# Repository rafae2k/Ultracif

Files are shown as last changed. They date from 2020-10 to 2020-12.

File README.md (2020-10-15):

<p align="center">
  Ultracif
</p></br>

### O UltraCif é um equipamento de descontaminação de máscaras através de luz ultravioleta para reutilização rápida e segura. Ele foi desenvolvido para amparar profissionais da saúde na luta contra a pandemia do COVID-19.

##### 1 - [Bibliografia](https://github.com/rafae2k/Ultracif/tree/main/Bibliografia)

  ###### Nesta seção você encontrará os principais artigos utilizados para pesquisa e desenvolvimento do Ultracif.

##### 1.1 - [Datasheet](https://github.com/rafae2k/Ultracif/tree/main/Datasheet)
  
  ###### Nesta seção você encontrará os datasheets dos principais componentes utilizados no Ultracif.

##### 2 - [Dosimetria](https://github.com/rafae2k/Ultracif/tree/main/Dosimetria)
  
  ###### Nesta seção é apresentado o programa elaborado em MATLAB para geração dos dados e graficos de irradiancia baseados nos dados da fabricante de lâmpadas UVC OSRAM.

##### 3 - [CAD](https://github.com/rafae2k/Ultracif/tree/main/CAD)

  ###### Nesta seção você encontrará os arquivos 3D dos componentes do Ultracif.

##### 4 [Eletroeletronica](https://github.com/rafae2k/Ultracif/tree/main/Eletroeletronica)
  
  ###### Nesta seção você encontrará os arquivos relativos ao desenvolvimento do PCB da placa controladora e diagrama do circuito elétrico.

 ##### 4.1 - [Firmware](https://github.com/rafae2k/Ultracif/tree/main/Eletroeletronica/Firmware)
   
   ###### Nesta seção você encontrará os arquivos do código-fonte utilizados no firmware do Ultracif.
  
##### 5 - [Lista de Materiais](https://github.com/rafae2k/Ultracif/tree/main/Lista%20de%20Materiais)
   
   ###### Nesta seção você encontrará a lista com todos os materiais utilizados para montagem do Ultracif.

##### 6 - [Orientações Gerais](https://github.com/rafae2k/Ultracif/tree/main/Orienta%C3%A7%C3%B5es)
   
   ###### Nesta seção você encontrará todas as orientações necessárias para operação do equipamento.

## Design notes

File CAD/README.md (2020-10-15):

# CAD

#### Nesta seção você encontrará os arquivos 3D dos componentes do Ultracif.

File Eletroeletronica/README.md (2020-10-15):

# ELETROELETRONICA
  ###### Nesta seção você encontrará os arquivos relativos ao desenvolvimento da placa controladora e diagrama do circuito elétrico.

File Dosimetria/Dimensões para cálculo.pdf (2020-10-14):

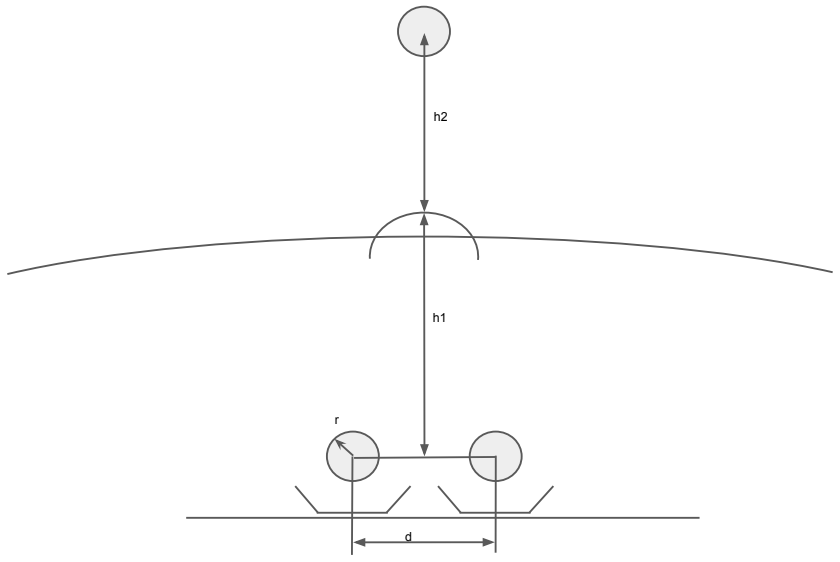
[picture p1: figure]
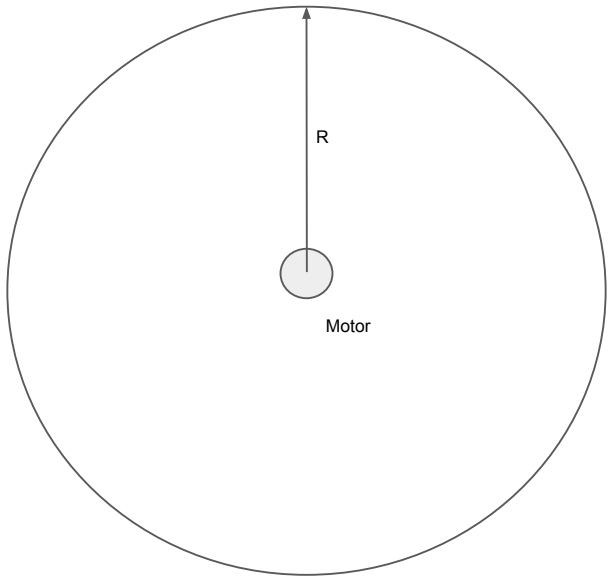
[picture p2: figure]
Motor R

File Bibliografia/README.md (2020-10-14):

# BIBLIOGRAFIA
  ###### Nesta seção você encontrará os principais artigos utilizados para pesquisa e desenvolvimento do Ultracif.

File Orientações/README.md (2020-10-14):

# ORIENTAÇÕES GERAIS
   ###### Nesta seção você encontrará todas as orientações necessárias para operação do equipamento.

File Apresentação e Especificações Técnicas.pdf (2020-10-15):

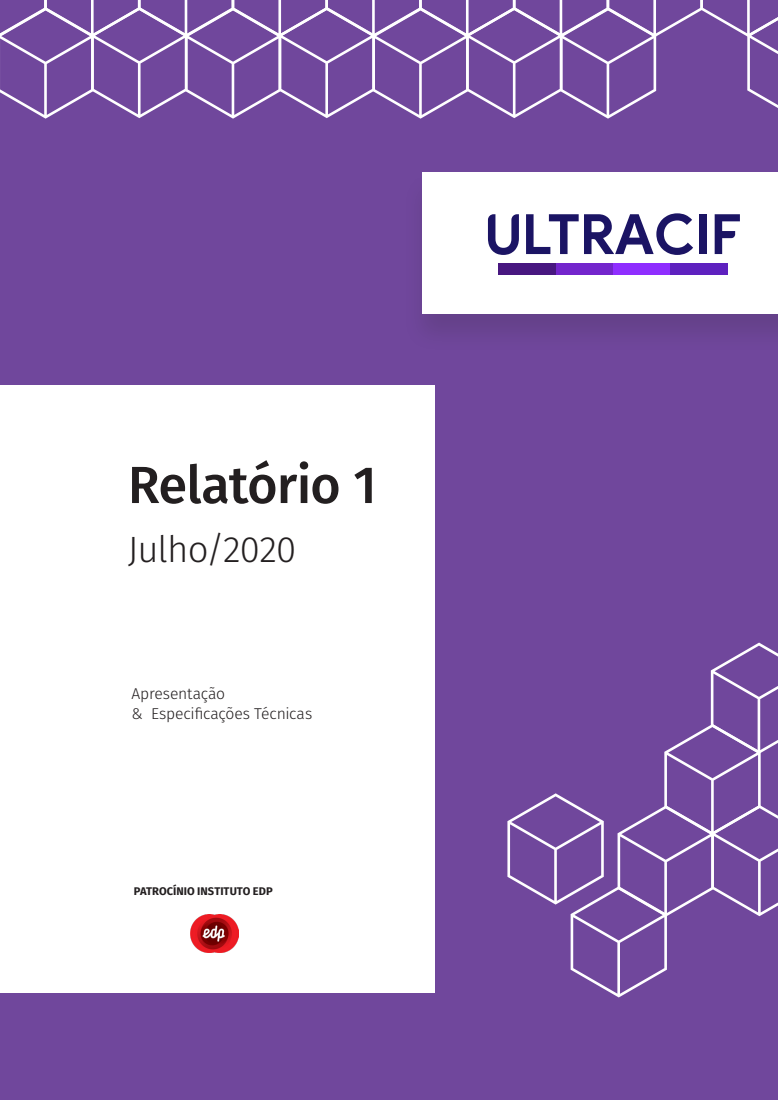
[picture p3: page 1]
Relatório 1; Julho/2020; Apresentação & Especificações Técnicas

PATROCÍNIO INSTITUTO EDP

No cenário de adversidades e imprevisibilidades em que o mundo se encontra, tem se tornado uma constante a busca por soluções inovadoras para os problemas correntes. É isso que norteia a Equipe ULTRACIF, formada por pessoas que acreditam no papel central da ciência e da tecnologia na geração de benefícios concretos para a sociedade.

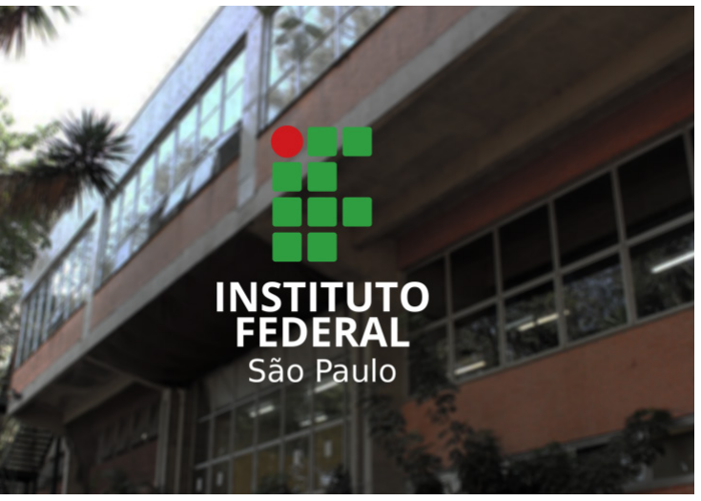
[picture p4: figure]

## Tergos / Bright Photomedicine

O Instituto Federal de Educação, Ciência e Tecnologia São Paulo (IFSP) é uma instituição pública federal especializada na oferta de educação científica, tecnológica e profissionalizante nas diferentes modalidades de ensino - técnico, superior e de pós-graduação. Fundada em 1909, como Escola de Aprendizes Artífices, é reconhecida tanto por sua excelência no ensino público gratuito de qualidade quanto pelo seu envolvimento em projetos capazes de promover benefícios e melhorias para a sociedade.

## Instituto Federal de São Paulo

A Bright Photomedicine é uma healthtech que combina big data, machine learning e inteligência artificial com a física e a medicina para criar o primeiro remédio digital do mundo. É afiliada da Tergos, empresa dedicada à pesquisa e ensino na mesma linha. Sua missão é propiciar aos pacientes alívio e cura da dor, de maneira eficaz, acessível, previsível e sem efeitos colaterais através da energia luminosa.

A equipe foi formada a partir de uma parceria entre o Instituto Federal de São Paulo (IFSP) e a Bright Photomedicine. Dessa união, surge o ULTRACIF, um equipamento inovador de desinfecção UV open-source, desenvolvido para amparar profissionais de saúde que têm lidado com a falta de equipamentos de proteção individual (EPI’s) na luta contra a pandemia do COVID-19.

# Sobre Institucional

2 | ULTRACIF

# ALEXANDRE CAMPO

Professor Titular do Instituto Federal de São Paulo – campus São Paulo Doutor em Engenharia Elétrica POLI-USP

# LUÍSA YAMAUCHI

Graduanda em Engenharia Naval -POLI-USP e Vice-Presidente do Centro Acadêmico de Engenharia Naval (CEN).

# RAFAEL FEITOZA

Graduando em Eng. de Controle e Automação
IFSP – campus São Paulo

# CADU PALMIERI

Engenheiro Eletrônico - IFSP Mestrando em
Engenharia Elétrica USP - EESC

# MARCELO SOUSA

Físico com doutorado em Low Level Light Therapy - Harvard Medical School CSO da empresa Bright Photomedicine

# Nosso Time

ULTRACIF | 3

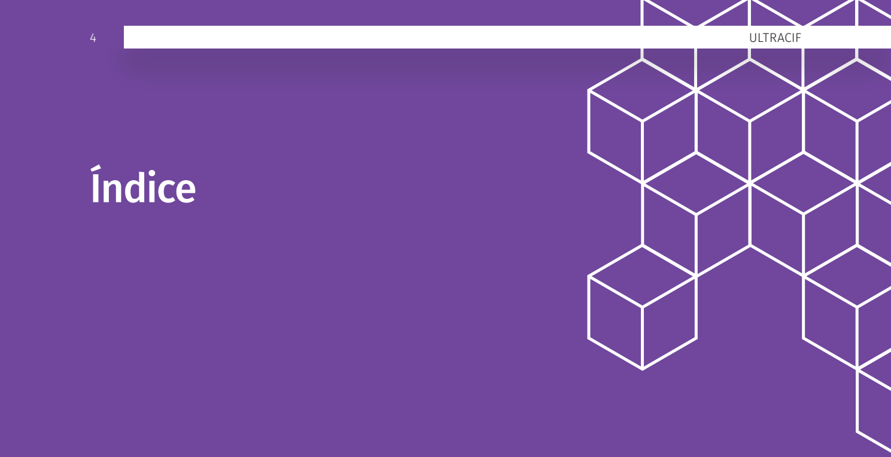
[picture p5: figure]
Índice

I. O Projeto | 05
II. Contexto / Justificativa | 07
III. Projeto Dosimétrico | 09
IV. Desenvolvimento / Modelos | 10
V. Componentes | 12
VI. Construção e Montagem | 14

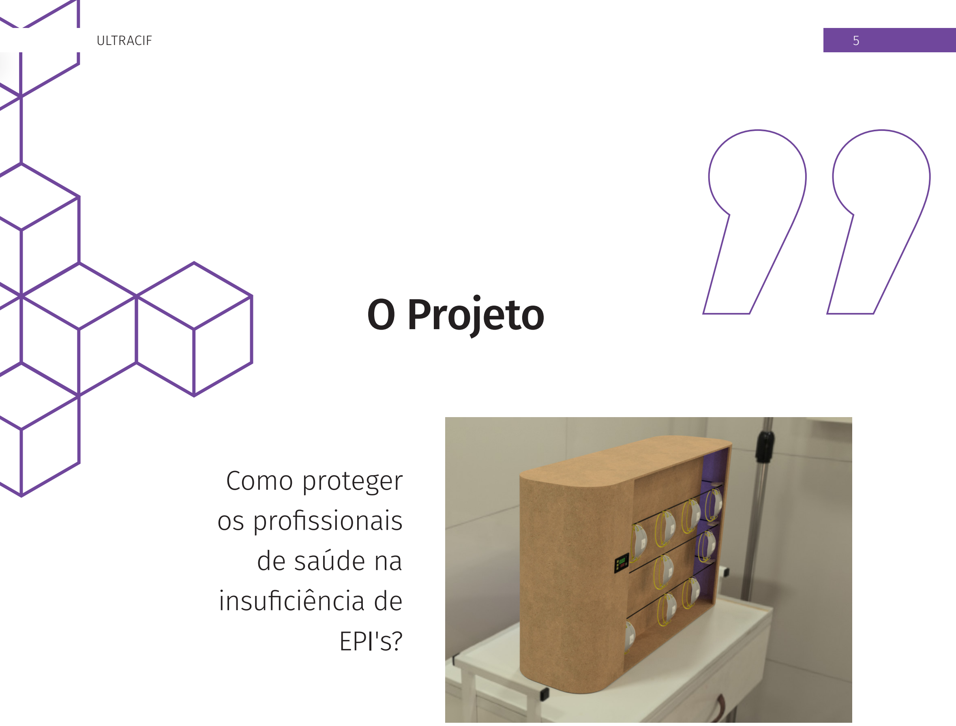
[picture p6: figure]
O Projeto; Como proteger os profissionais de saúde na insuficiência de EPI's?

A pandemia da COVID-19 tem
causado | grande | impacto | na
sociedade durante o ano de 2020, sobrecarregando o sistema de saúde e seus profissionais por todo o mundo.

Devido à carência de máscaras do tipo N95/PFF2-S, essenciais na proteção contra o vírus, surge a necessidade de se pensar em formas de atender a essa demanda, sendo uma delas o uso de dispositivos de descontaminação de equipamentos de proteção individual, possibilitando o reuso mais adequado destes.

Dentro | deste | contexto, | tem-
se como proposta de solução o desenvolvimento de um sistema de descontaminação de máscaras através de irradiação ultravioleta
germicida | (IUVG): | o ULTRACIF.

O projeto envolve duas principais inovações que definem a originalidade do equipamento. A primeira está relacionada à garantia de segurança no uso, uma vez que a radiação ultravioleta do tipo C é nociva aos tecidos humanos. Esta proteção consiste em uma câmara de descontaminação confinada para

ULTRACIF: DESCONTAMINAÇÃO RÁPIDA E SEGURA DE MÁSCARAS.

as máscaras, de modo que o usuário nunca fique exposto à UVC. A segunda trata do sistema de alimentação contínua das máscaras, permitindo que novas máscaras a serem descontaminadas sejam inseridas no processo sem a necessidade
de | interrupção | do | sistema.
A velocidade de movimentação do sistema de transporte de máscaras garante a exposição à dosagem correta de irradiação ultravioleta germicida, além de expor a máscara a diferentes ângulos de incidência da radiação.

# Um trabalho seguro é

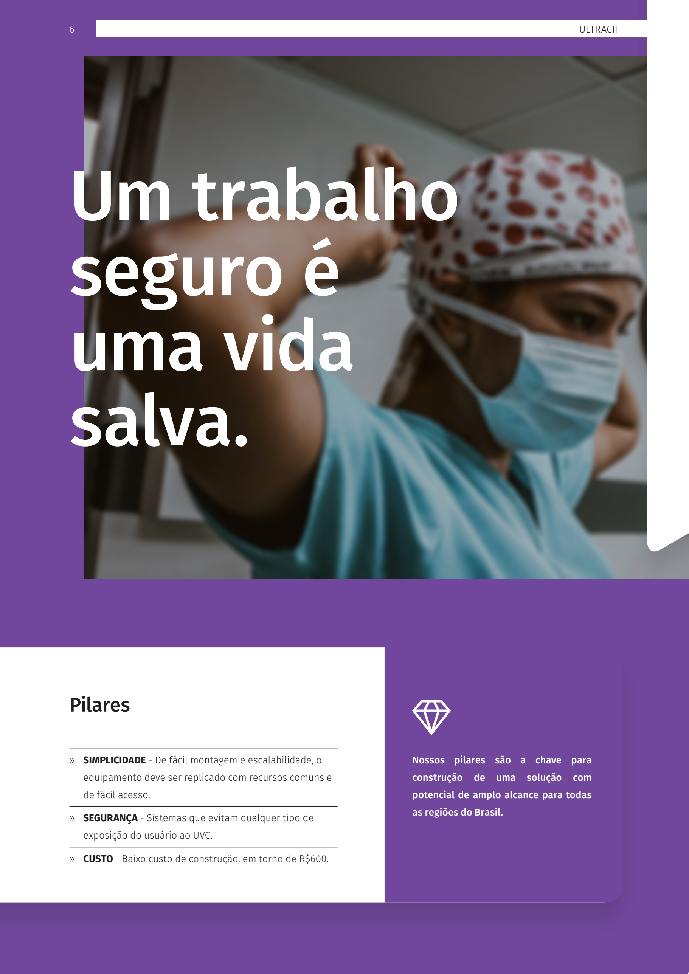
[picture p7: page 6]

# uma vida

salva.

# Pilares

» SIMPLICIDADE - De fácil montagem e escalabilidade, o equipamento deve ser replicado com recursos comuns e de fácil acesso.
» SEGURANÇA - Sistemas que evitam qualquer tipo de exposição do usuário ao UVC.
» CUSTO - Baixo custo de construção, em torno de R$600.

Nossos pilares são a chave para construção de uma solução com potencial de amplo alcance para todas as regiões do Brasil.

O fornecimento adequado de máscaras para os trabalhadores da saúde durante a pandemia global é um problema urgente de saúde pública.

O uso de máscaras N95 é recomendado como um dos principais meios de proteção dos profissionais de saúde (Mills et al., 2018)¹. Considerando que a pandemia do vírus SARS-CoV-2 tem seu principal canal de transmissão através das vias respiratórias, a disponibilidade deste EPI passa a ser um fator crítico. A alta demanda por este tipo de equipamento tem provocado sua falta em diversas localidades, tendo sido destacadas orientações para seu reuso de acordo com a ²NOTA TÉCNICA GVIMS/GGTES/ANVISA Nº 04/2020:

“O tempo de uso da máscara N95/PFF2 ou equivalente, em relação ao período de filtração contínua do dispositivo, deve considerar as orientações do fabricante. O número de reutilizações da máscara, pelo mesmo profissional, deve considerar as rotinas orientadas pelas CCIHs do serviço de saúde e constar no Protocolo.”

Segundo o boletim técnico de um fabricante de máscaras N95 (Decontamination Methods for 3M Filtering, Revisão 7)³, o processo de descontaminação deve atender aos seguintes requisitos: inativar o organismo alvo, tal como o vírus que causa COVID-19; não danificar a propriedade filtrante do dispositivo; não afetar a forma do dispositivo, impedindo seu correto uso; e ser um procedimento que garanta a segurança do usuário do respirador.

Um dos métodos apontados como efetivos para este processo é através do uso de irradiação ultravioleta germicida (IUVG). Segundo (Dai et al., 2012)⁴, a irradiação ultravioleta germicida é uma irradiação eletromagnética com um comprimento de onda compreendido na faixa entre 100 nm e 400 nm, sendo mais curto que a luz visível e mais longo que o raio-X.

# Contexto / Justificativa

¹MILLS, D. et al. Ultraviolet germicidal irradiation of influenza-contaminated N95 filtering facepiece respirators. American journal of infection control, v. 46, n. 7, p. e49– e55, jul. 2018.
²Nota técnica GVIMS/GGTES/ANVISA nº 04/2020 orientações para serviços de saúde: medidas de prevenção e controle que devem ser adotadas durante a assistência aos casos suspeitos ou confirmados de infecção pelo novo coronavírus (SARS-CoV2).
³Decontamination Methods for 3M Filtering Facepiece Respirators such as N95 Respirators. Technical Bulletin, Junho de 2020. Revisão 7
⁴DAI, T. et al. Ultraviolet C irradiation: an alternative antimicrobial approach to localized infections? Expert review of antiinfective therapy, v. 10, n. 2, p. 185–195, fev. 2012.

# Uma alternativa ao reuso de máscaras consiste na utilização de métodos de descontaminação

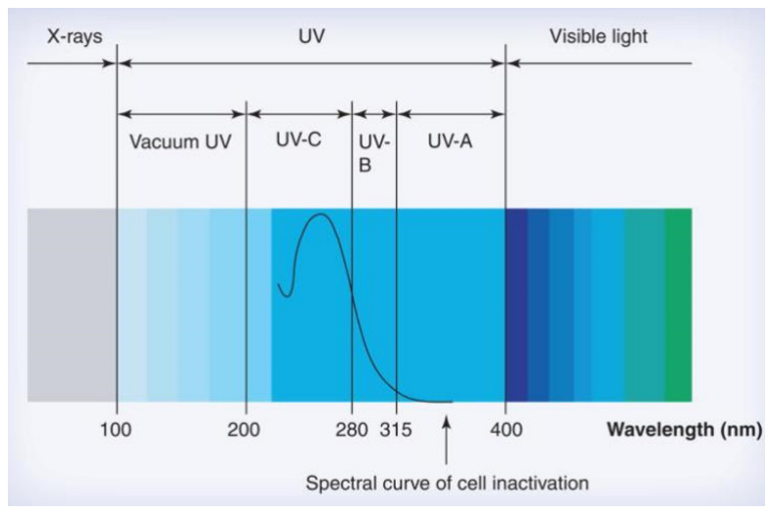
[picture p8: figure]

Figura 1: Espectro de radiação e curva de absorção e inativação de celulas virais.

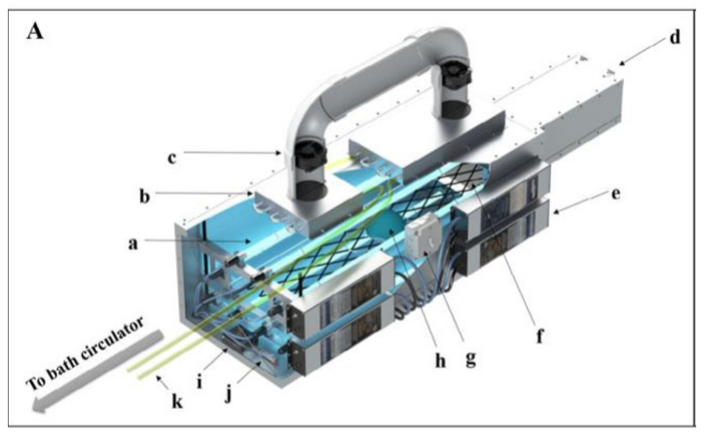
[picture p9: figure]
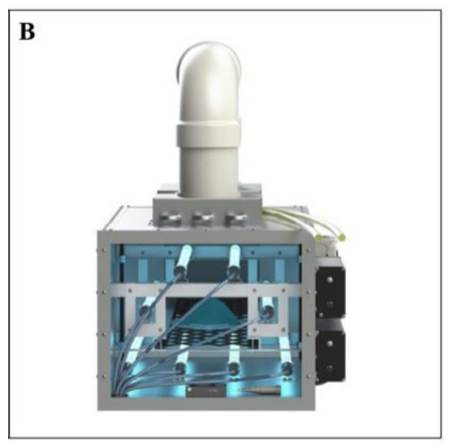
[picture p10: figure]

O trabalho apresenta a metodologia para a determinação da dosagem de radiação necessária para o processo de descontaminação, sendo apresentados os cálculos de acordo com a irradiância de uma lâmpada IUVG comercial:

O espectro do ultravioleta é dividido em quatro faixas, sendo que a faixa UVC é aquela compreendida entre 200 nm e 280 nm. Esta faixa de radiação tem a característica de ser absorvida com facilidade por ácidos nucleicos de organismos vivos, sendo uma faixa letal para estes.

O pico da ação germicida ocorre em 254 nm, sendo conhecida como espectro germicida, devendo ser utilizada com cuidados para evitar sua ação sobre tecidos humanos.

A geração do IUVG pode ser feita através de lâmpadas de vapor de mercúrio de baixa pressão de baixo custo. Recentemente também foram desenvolvidos light emitting diodes (Leds) que emitem radiação germicida, possibilitando um uso mais amplo deste tipo de ação.

Mills et al. (2018)¹ apresenta um estudo em que máscaras N95 de diversos fabricantes foram contami-nadas com vírus do tipo influenza (H1N1), tendo sido posteriormente submetidas a uma densidade de potência de 1 J/cm² por aproximadamente um minuto, sendo observada uma significativa redução, maior do que 3 log. No referido experimento foi construída uma câmara em que as máscaras foram inseridas para a execução do procedimento de descontaminação, conforme apresentado ao lado.

Figura 2: Dispositivo para a descontaminação de máscaras do tipo N95 por irradiação ultravioleta germicida (IUVG).

A dosagem de irradiação ultravioleta germicida (IUVG) deve ser calculada corretamente para que possam ser eliminados os patógenos presentes no material a ser descontaminado. Os cálculos da dosagem de IUVG dependem da fonte de radiação utilizada. No caso do modelo de lâmpada adotado para o projeto (OSRAM UV-C Puritec-HNS), tem-se que há emissão de radiação principalmente no comprimento de onda classificado como UV-C, de 254 nm.
De acordo com o fabricante, cada lâmpada possui um gráfico específico que descreve a irradiância em função da distância da lâmpada, sendo que o decaimento exponencial desta grandeza implica no uso de dois gráficos diferentes para representar a queda da dimensão. Num primeiro gráfico, o fabricante descreve a irradiância em W/m² em um raio de 0 a 0,5m de distância da superfície da lâmpada. Num segundo gráfico a irradiância é apresentada na faixa entre 0,5 m e 3 m de distância.
Para calcular a dosagem de IUVG na máscara, foi necessário determinar a função que melhor representa a irradiância em função da distância. Este cálculo foi desenvolvido para uma lâmpada OSRAM G13 através do programa MATLAB e é apresentado a seguir:

# Projeto Dosimétrico

Considerando que a lâmpada tem 1,3 cm de raio e aproximadamente 43,8 cm de comprimento, com potência total de 4W na faixa UV-C, nota-se que a irradiância em sua superfície é de 110 W/m².

A irradiância da lâmpada tubular se espalha ao redor da mesma de acordo com a função acima representada. Dessa forma, pode-se calcular a irradiância numa superfície perpendicular à lâmpada G13, de acordo com a figura a seguir:

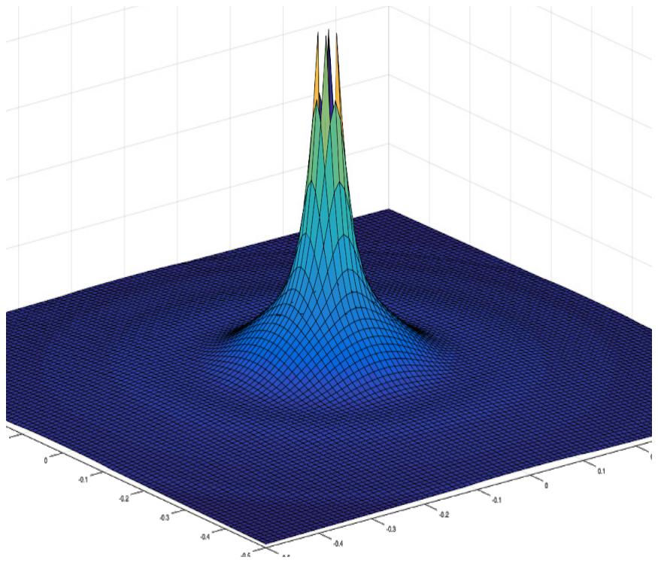
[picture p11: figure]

Figura 4 - Irradiância da Lâmpada UVC 15W OSRAM HNS

Deste modo é possível, definir a velocidade que o sistema de transporte das máscaras deverá ter para que estas recebam a dosagem de IUVG desejada.

No momento atual, o valor da dosagem calculada para um objeto movendo-se a 5 cm/s diante da lâmpada G13 chega a 70 Ws/m². O projeto deverá se desenvolver para definir a velocidade de movimentação que garante a descontaminação da máscara, considerando o patógeno Sars-CoV2.

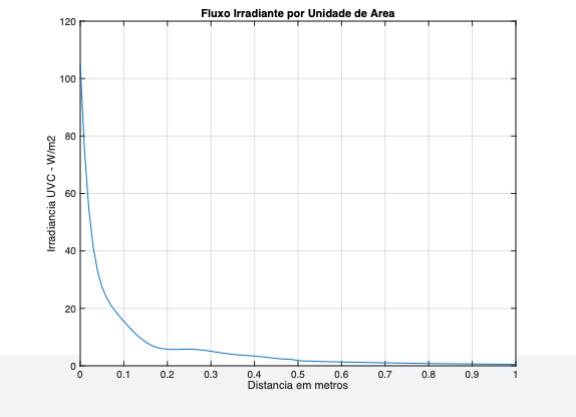
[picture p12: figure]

Figura 3 - Fluxo Irradiante por Unidade de área.

Este mecanismo realiza o percurso que transporta a máscara contaminada do ponto de entrega ao ponto onde a exposição à luz ultravioleta ocorre, realizando assim o efeito germicida. É composto por um motor do tipo "passo", que realiza a movimentação de um sistema de engrenagens e de uma correia de transporte.

# SISTEMA DE TRANSPORTE

O sistema de controle garante o funcionamento do dispositivo realizando os acionamentos das lâmpadas, rotação do mecanismo de transporte por meio do motor e a verificação dos dispositivos de segurança. Ele é composto de um microcontrolador, que executa o código de controle. A interação do usuário com o equipamento acontece através de botões e de um display, que informam sobre seu funcionamento e sua manutenção.

# SISTEMA DE CONTROLE

Pensando na segurança, alguns itens estão sendo implementados para garantir a proteção do usuário e a eficiência do equipamento. Foram colocados sensores UVC, que alertam o usuário se a radiação está sendo emitida e informam em caso de possíveis falhas, como "lâmpadas queimadas", para que a manutenção seja feita, sensores de contagem de pulso para medir a velocidade do sistema de rotação das máscaras, e sensores de abertura, que desativam o sistema caso a estrutura seja aberta durante o funcionamento.

# DISPOSITIVOS DE SEGURANÇA E AUTOTESTE

# Desenvolvimento Modelos

Para o desenvolvimento dos modelos iniciais, buscou-se atingir os seguintes pontos principais: alta disponibilidade dos materiais no mercado, facilidade de montagem e manutenção e simplicidade no funcionamento do dispositivo.

O princípio de funcionamento dos modelos ULTRACIF é sempre garantir a segurança quanto à exposição à radiação ultravioleta, enquanto mantém o equipamento funcionando ininterruptamente para que os profissionais de saúde possam descontaminar seus EPI’s em poucos segundos, sem a necessidade de tocar em nada além de suas próprias máscaras. Isso é obtido através de um projeto eletroeletrônico e mecânico, que agrega, além da estrutura-base, sistemas que conversam entre si para garantir o funcionamento do equipamento de forma segura.

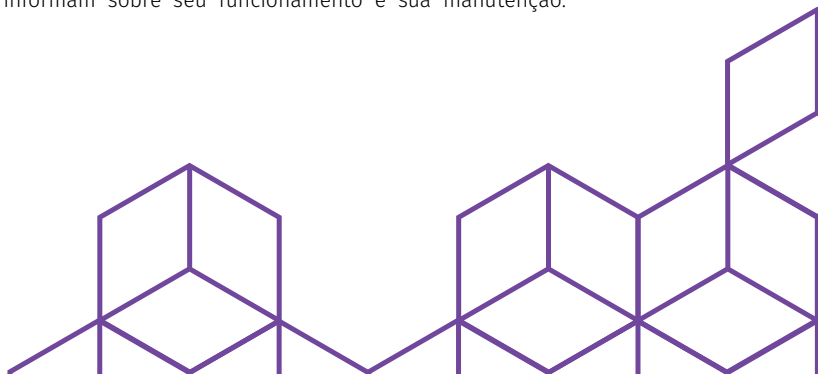
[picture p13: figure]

### Estrutura

Foram desenvolvidos três modelos buscando averiguar o melhor sistema para a movimentação das máscaras no interior do dispositivo. Além disso, diversos materiais também serão analisados, com o objetivo de garantir o melhor desempenho estrutural e de resistência à radiação UV. Também procura-se obter o melhor custo-benefício do produto.

### MATERIAIS

PETG
ABS
Polipropileno
MDF

### Opções

Movimento circular e linear atráves de polias

Modelo 2
600x350x500x3mm

Modelo 1
600x350x400x3mm

Modelo 3
600x350x500x3mm

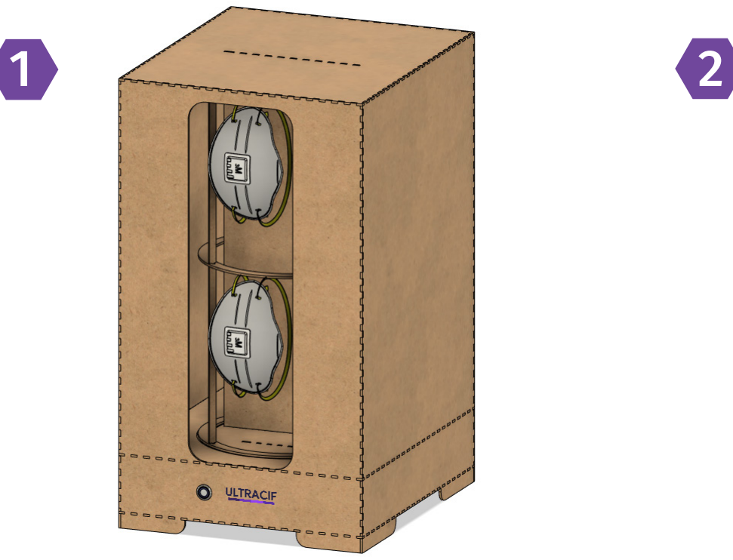
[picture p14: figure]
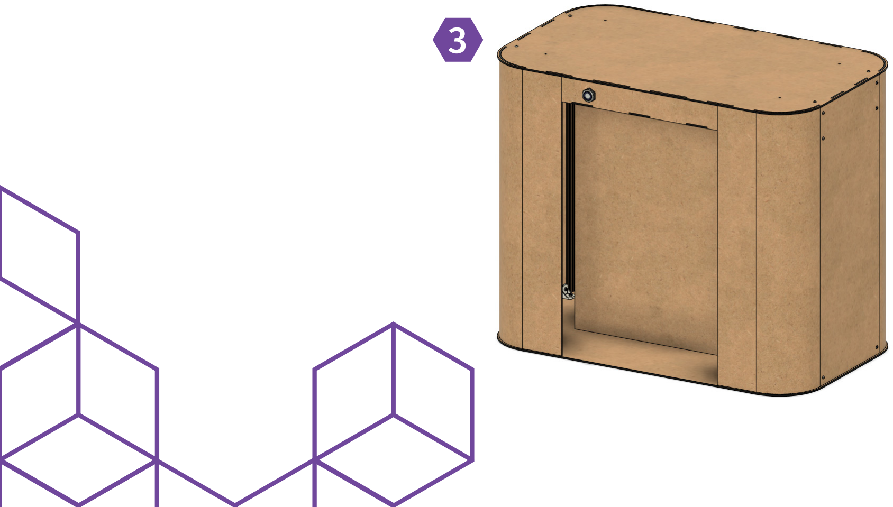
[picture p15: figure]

As lâmpadas germicidas emitem radiação ultravioleta do tipo C e são feitas em tudo de quartzo especial transparente que permite a transmissão da radiação UVC.

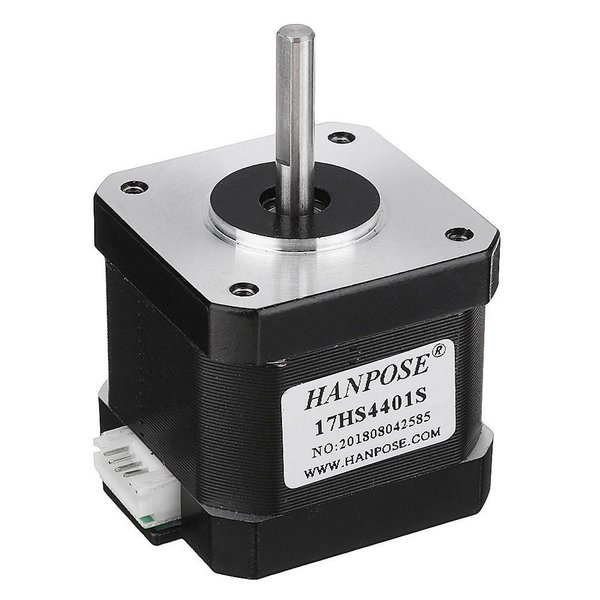
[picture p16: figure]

Um motor de passo é um tipo de motor elétrico usado quando algo tem que ser posicionado muito precisamente ou movimentado de um ângulo exato, permitindo alto controle de sua velocidade.

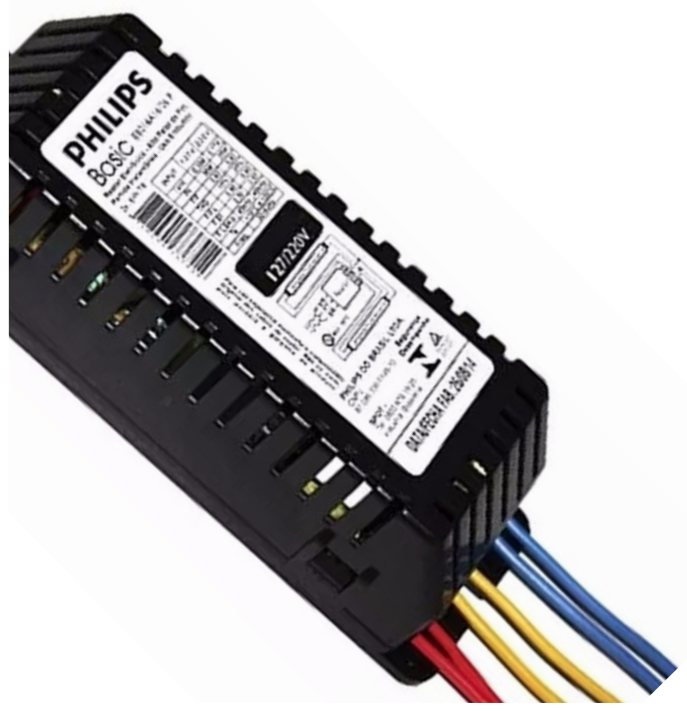
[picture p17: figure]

Produz um impulso elétrico de alta tensão, capaz de iniciar o processo de ionização. Com a lâmpada em operação, limita a corrente, permitindo seu funcionamento seguro.

Responde eletricamente à radiação no espectro UVC, gerando um sinal analógico proporcional à intensidade captada, a partir do qual é possível monitorar a radiação interna do equipamento.

## Lâmpada UVC

osram hns puritech 15w

## Motor de passo

12V 1.7A 4Kgf.cm

## Lâmpada UVC

2x15W Alto FP.

## Sensor UVC

composto de um foto diodo

# Desenvolvimento Componentes

# Eletroeletrônica

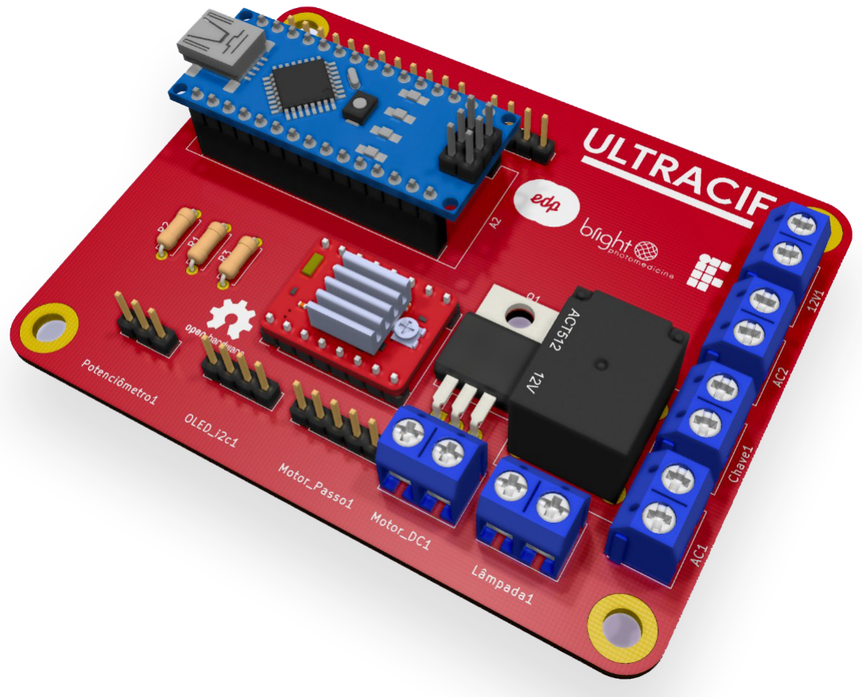
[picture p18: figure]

» Microcontrolador Arduino NANO

» Driver de motor

» Relé eltromagnético

» Suporte a display

» Sensor UVC

» Sensor de proximidade

» Fonte de alimentação

O sistema eletrônico consiste de uma placa microcontrolada contendo todos os periféricos para acionamento e leitura dos sensores. A placa de circuito impresso, mostrada na figura acima, agrega todos os componentes eletrônicos, permitindo assim os acionamentos e o sensoriamento.

A representação dos dispositivos e de sua arquitetura organizacional é ilustrada a seguir, no Diagrama de Blocos Eletrônico. Neste arranjo, é possível observar todos os elementos que compõem o sistema, e como eles interagem entre si.

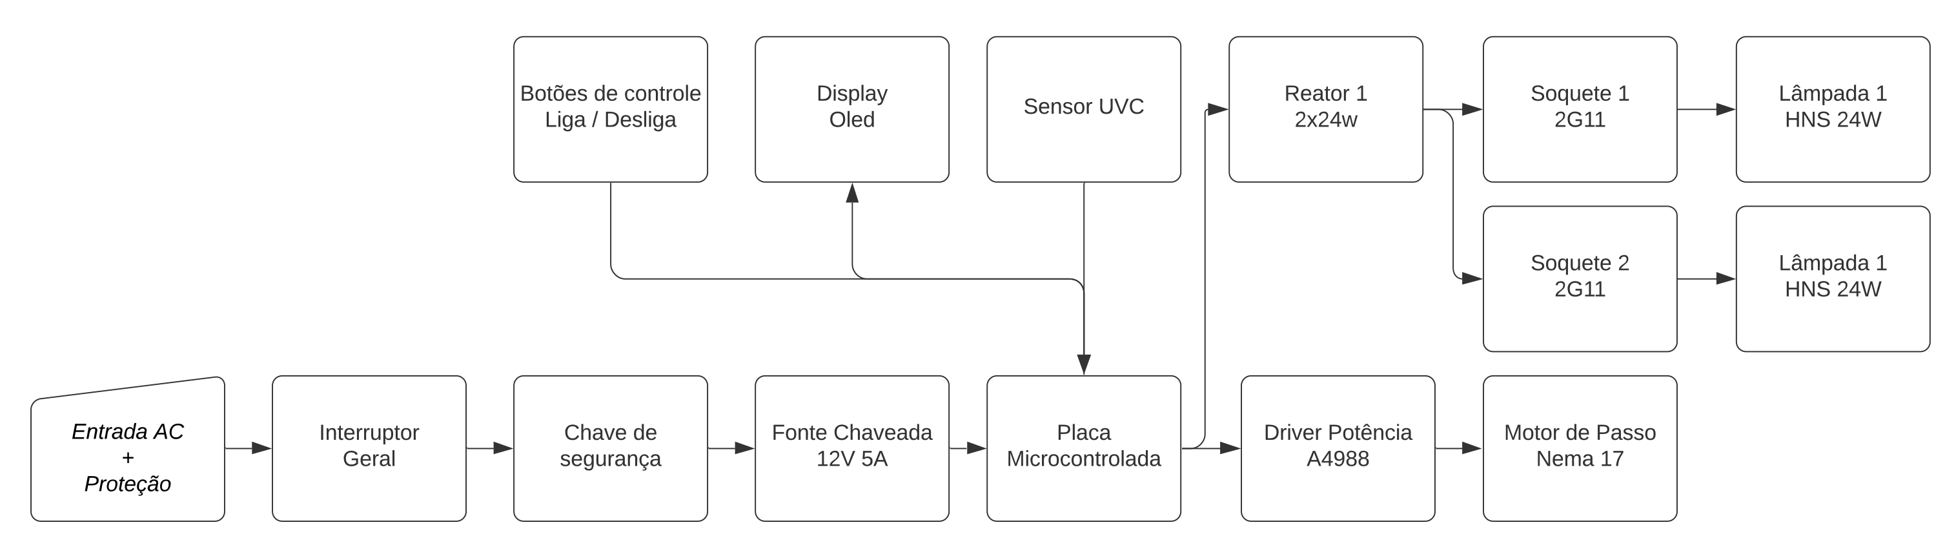
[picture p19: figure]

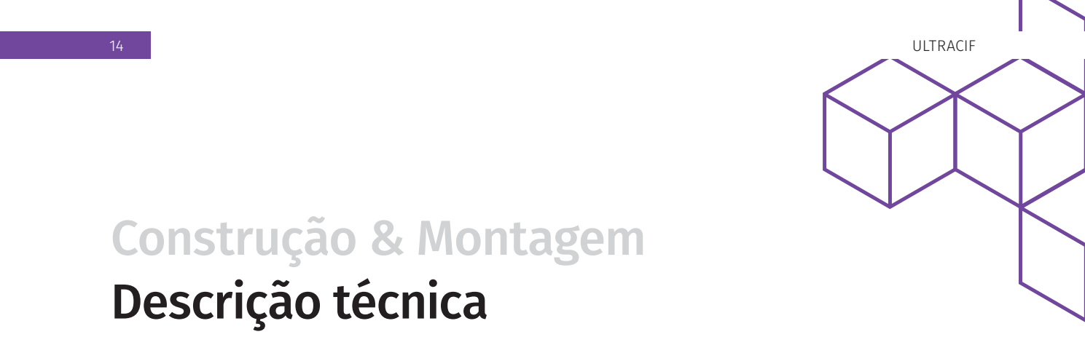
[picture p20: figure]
Construção & Montagem Descrição técnica

O sistema foi pensado de forma a ser replicado por pessoas com instinto maker, com componentes de construção acessíveis e intercambiáveis de acordo com a disponibilidade local. Basta uma máquina de corte a laser ou fresa para se reproduzir a estrutura do dispositivo.

A montagem segue um manual que contempla 3 principais áreas do projeto:

ESTRUTURA: feita em MDF, com encaixes para fácil montagem, propicia robustez e baixo custo.

SISTEMA CARROSSEL: em sua maior parte também em MDF com alguns suportes metálicos compõem o conjunto que realizará o translado da máscara contaminada até o elemento germicida e trará a máscara esterilizada ao usuário.

ELETRÔNICA: O cérebro do equipamento contém um sistema microcontrolado que faz o controle dos elementos responsáveis pelo processo de descontaminação, aciona as lâmpadas germicidas, controla o movimento da mecânica de transporte e do sistema de segurança.

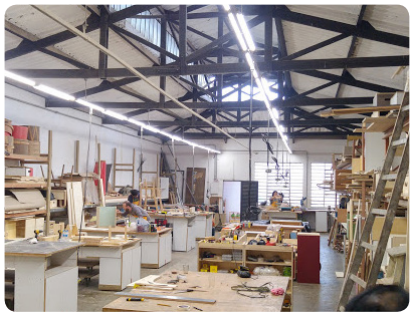
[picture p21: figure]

À direita, foto da Garagem FabLab, espaço utilizado para a realização dos cortes das peças, que possibilitou o processo iterativo de testes e redesign, bem como a identificação e correção de erros on-the-go.

# Impressão em 3D

A impressão 3D, também chamada de fabricação aditiva, é uma família de processos que produz objetos ao adicionar material em camadas que correspondem a seções transversais sucessivas de um modelo 3D. Nossos modelos utilizarão esta tecnologia para fabricação rápida das peças que compõem o sistema carrossel de transporte das máscaras. As peças dos protótipos foram elaboradas no programa Fusion 360 e sua produção foi possível graças ao uso de uma máquina CNC de corte a laser, comum em espaços maker, de prototipagem e produção industrial em todo país.
12 80g
Peças Impressas | PETG

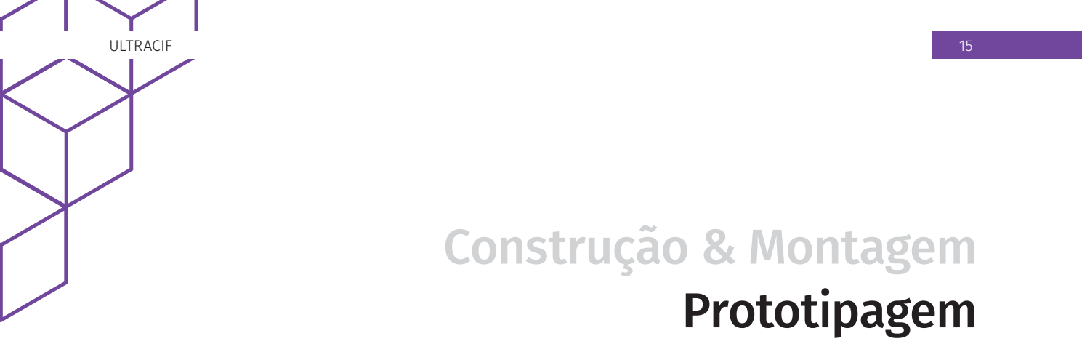
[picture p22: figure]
Construção & Montagem Prototipagem
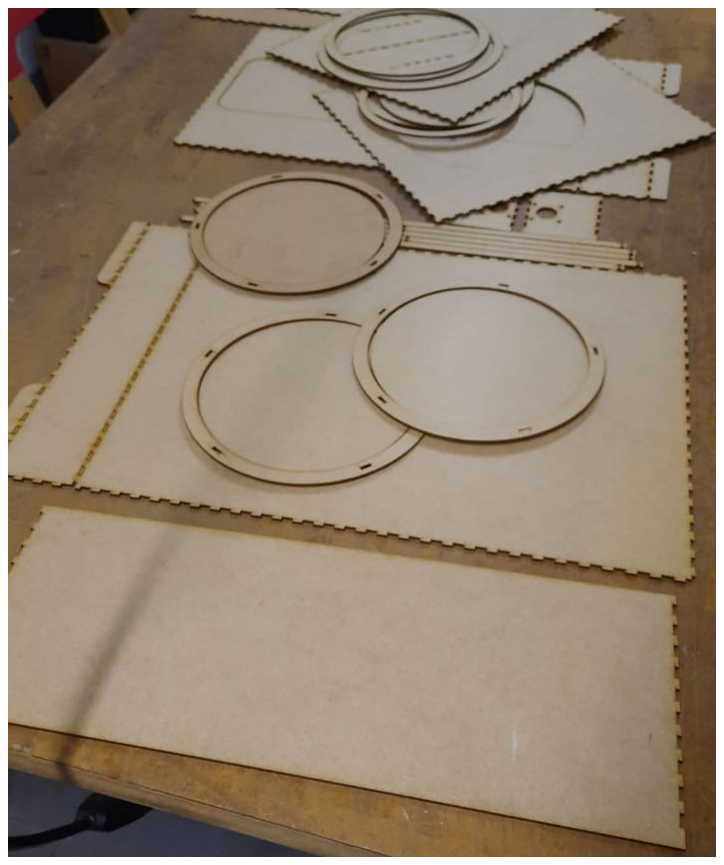
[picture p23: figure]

O projeto dos protótipos foi idealizado para permitir sua rápida montagem, com o mínimo de ferramentas necessárias. Cada peça tem sua ordem e posição de montagem. Com todas as peças à mão, o equipamento fica pronto para esterilizar as máscaras.

Um segundo modelo, mostrado nas imagens, utiliza cantoneiras de 0,75mm para fixação de suas peças. Este tipo de montagem, permite um visual mais limpo e rígido, sem o uso de cola instantânea para fixação das partes.

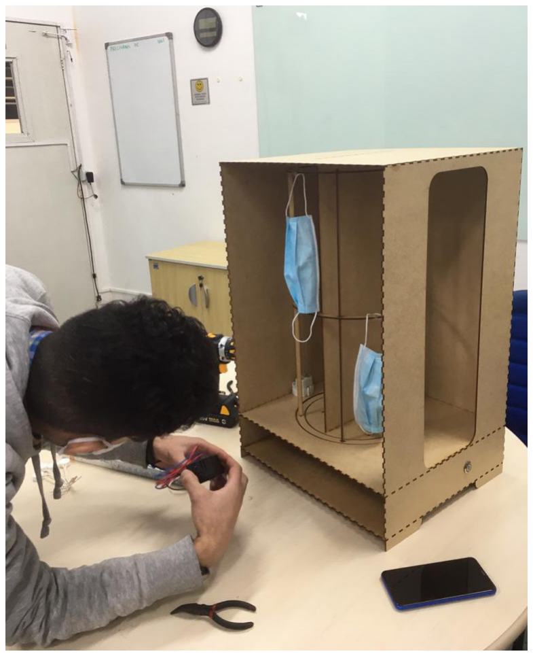
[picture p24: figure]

A montagem dos dispositivos foi feita no Laboratório de Controle Aplicado do IFSP no bairro do Canindé (SP). Já o corte das peças dos protótipos foi feito em parceria com o Garagem FabLab no bairro da Barra Funda (SP). Um dos grandes desafios enfrentados foi em relação à logística. Com os diversos integrantes do grupo espalhados pela cidade e região metropolitana de São Paulo, foi preciso superar a distância e o risco da contaminação pelo transporte público, enquanto seguíamos os protocolos de saúde.

ULTRACIF 2020

Relatório parcial de medição
enviado ao Instituto EDP
relativo ao EDITAL
EDP SOLIDÁRIA COVID-19

TODOS OS DIREITOS RESERVADOS

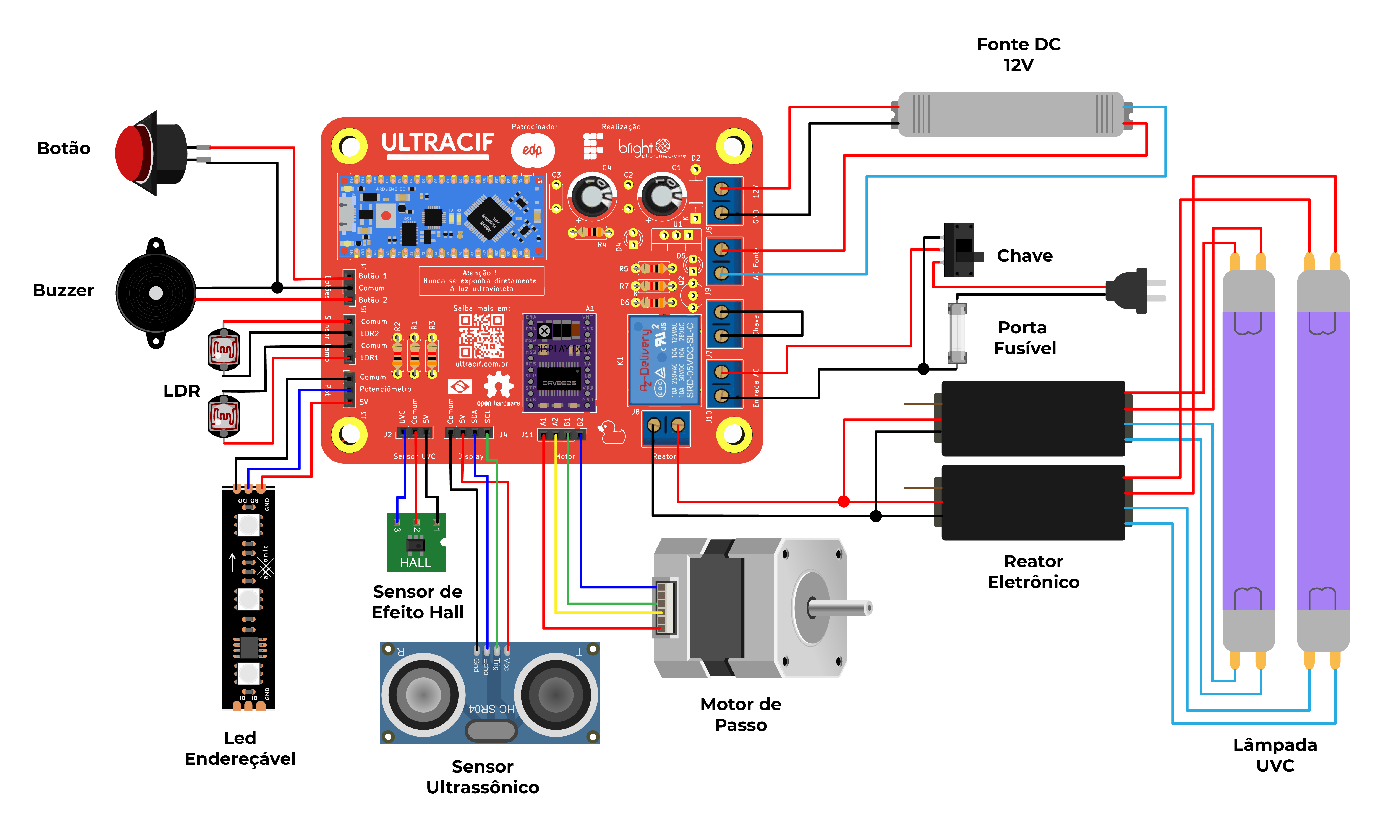
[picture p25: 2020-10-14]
Eletroeletronica/Diagrama elétrico.png

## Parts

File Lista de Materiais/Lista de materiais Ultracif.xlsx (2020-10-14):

Descrição | Referencia | Quantidade
Eletronica - PCB
Driver Motor de Passo | DRV8825 | 1
Arduino nano |  | 1
Capacitor | 100nF 50V | 2
Capacitor | 100uF 16V | 2
Diodo | 1N4001 | 1
Led Verde |  | 1
Led Vermelho |  | 1
Diodo | 1N4148 | 1
Conector modu 3 vias |  | 3
Conector modu 4 vias |  | 4
Borne 2 vias |  | 5
Relé 12V |  | 1
Transistor |  | 1
Resistor | 3k3 1/4W | 2
Resistor | 100 1/4W | 1
Resistor | 1k 1/4W | 3
Regulador 5V | LM7805 | 1
PCB |  | 1
Diversos
Motor de passo | 17HS4401 | 1
Sensor Efeito hall | KY-003 | 1
Ima neodimio | 10x3mm | 1
Sensor Ultrassonico | HC-SR04 | 1
LDR | 5mm | 2
Botão Pulsador |  | 1
Botão Gangorra |  | 1
Porta Fuzil |  | 1
Rabicho 2 vias | 2 metros | 1
Cabo 0,75mm | metros | 8
Reator Eletronico | 60w | 2
Fusivel de vidro 5x20 | 3A | 1
Cabo Flat | metros | 1
Malha Nautica | metros | 2
Fita Aluminizada | metros | 1.2
Soquete Lampada | 2g11 | 2
Lampada UVC | 60W 2G11 | 2
MDF Laminado | 3mm | N/A
Rolamento | 608 ZZ | 1
Parafusos | M3x10mm | 32
Impressão 3D
Suporte rolamento | PETG | 1
Bucha rolamento | PETG | 1
Suporte Aro Rotatorio | PETG | 1
Fixador 90° | PETG | 12
Prendedor de cabos | PETG | 8
Gancho mascara | PETG | 1
Pinos de suporte PCB | PETG | 4
Suporte Lampada T8 | PETG | 4
Suporte Lampada T8 com LDR | PETG | 4

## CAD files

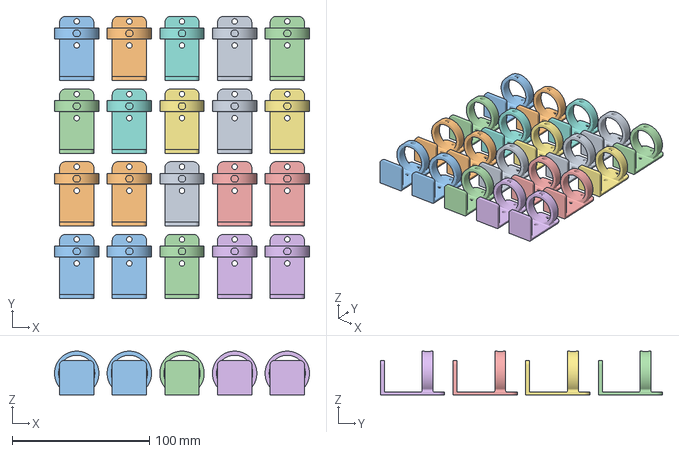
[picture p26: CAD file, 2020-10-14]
CAD/Impressao 3D/3MF/Suporte Lampada g13 com LDR - 20 PEÇAS - IMPRIMIR 2 LOTES.3mf
186.0 x 206.0 x 31.9 mm

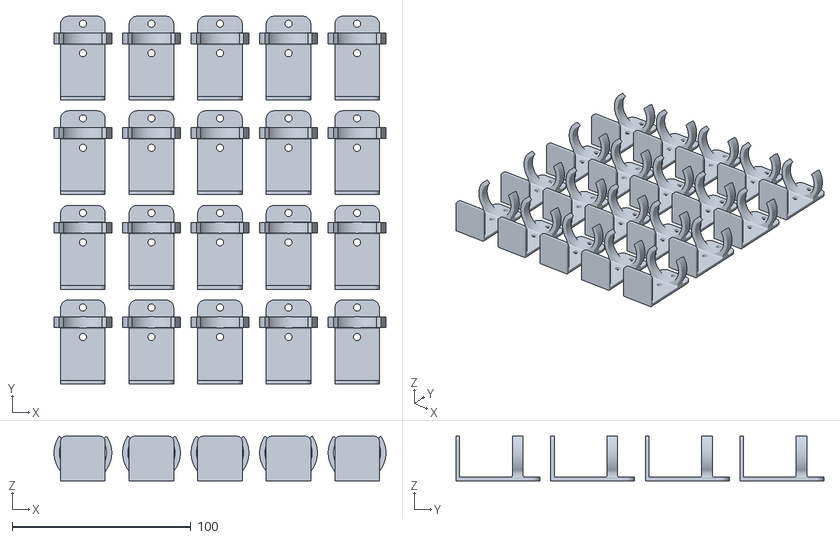
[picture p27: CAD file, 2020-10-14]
CAD/Impressao 3D/STL/Done/Suporte Lampada g13 - 20 PEÇAS - IMPRIMIR 2 LOTES.stl
186.0 x 206.0 x 25.0

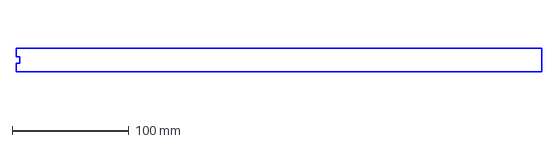
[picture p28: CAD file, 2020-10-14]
CAD/Plano de Corte/Peças Individuais/Externo/LAMP 400 - Aleta 1.dxf
450.1 x 20.2 mm

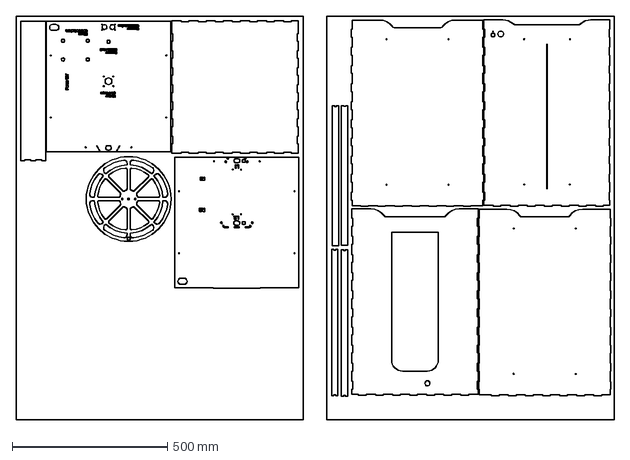
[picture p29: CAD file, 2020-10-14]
CAD/Plano de Corte/Plano de corte Completo - 1300x925x3mm.dxf
1925.0 x 1300.0 mm

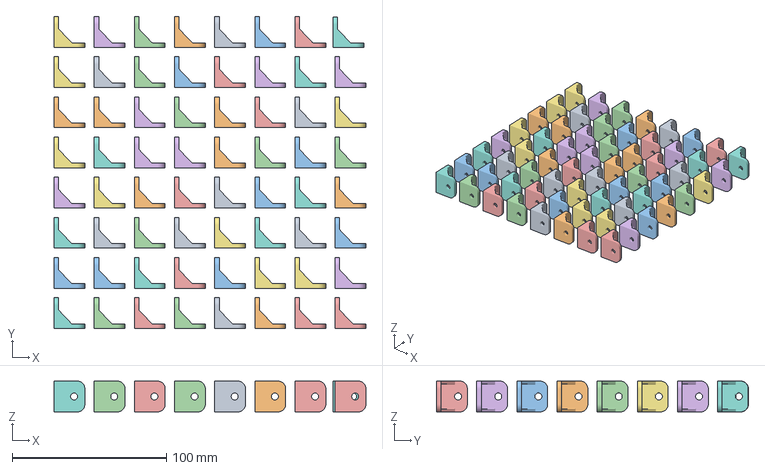
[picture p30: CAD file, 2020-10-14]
CAD/Impressao 3D/3MF/Fixador 90 graus - 64 PEÇAS - IMPRIMIR 2 LOTES.3mf
202.0 x 202.0 x 20.0 mm
Fixador 90 graus.stl x 2

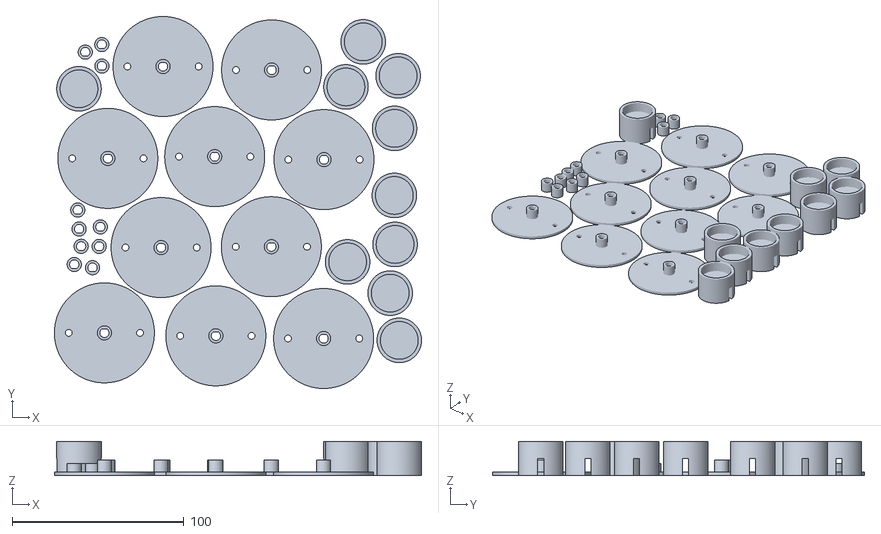
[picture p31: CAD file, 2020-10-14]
CAD/Impressao 3D/STL/Done/Bucha Rolamento + Suporte Rolamento + Suporte Aro - IMPRIMIR 1 LOTE.stl
214.1 x 216.9 x 20.0

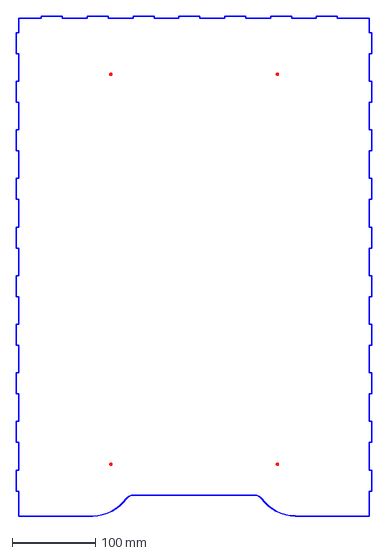
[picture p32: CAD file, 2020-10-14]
CAD/Plano de Corte/Peças Individuais/Externo/LAMP 400 - Lateral Direita.dxf
426.1 x 600.2 mm

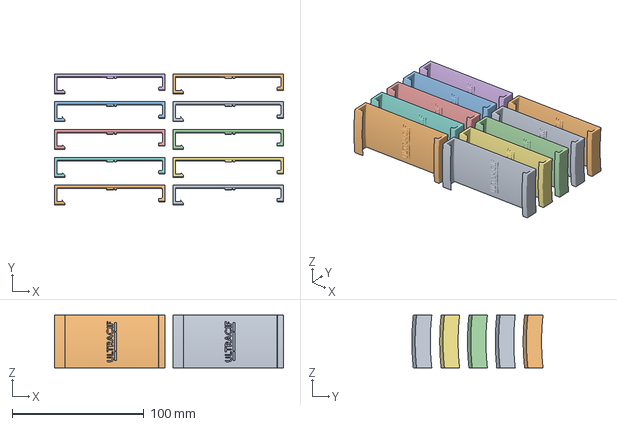
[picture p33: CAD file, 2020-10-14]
CAD/Impressao 3D/3MF/Gancho Mascara - 10 PEÇAS - 1 LOTE.3mf
174.0 x 99.7 x 40.0 mm

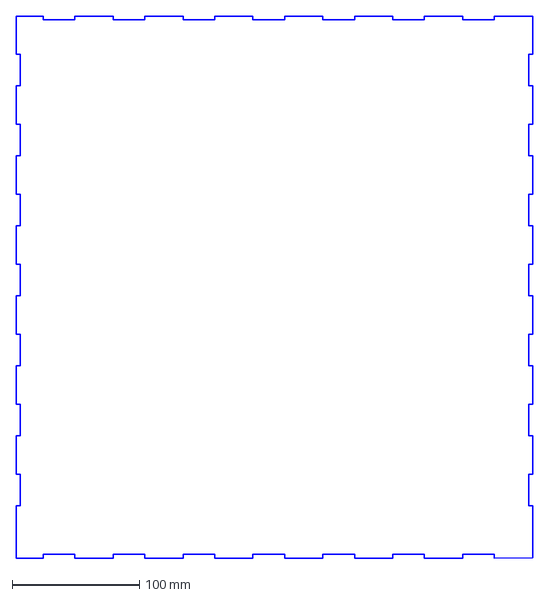
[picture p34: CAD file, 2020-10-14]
CAD/Plano de Corte/Peças Individuais/Externo/LAMP 400 - Topo Superior.dxf
406.2 x 426.2 mm

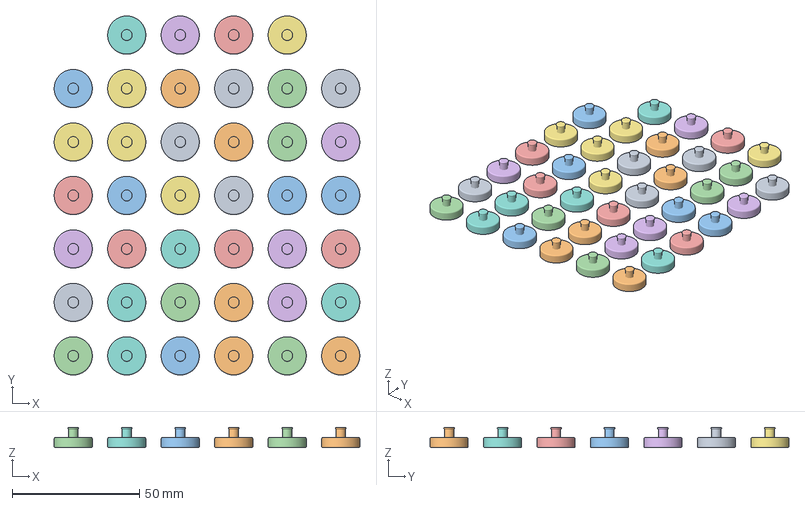
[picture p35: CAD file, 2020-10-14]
CAD/Impressao 3D/3MF/Pino Suporte PCB - 1 LOTE.3mf
120.0 x 141.0 x 8.00 mm

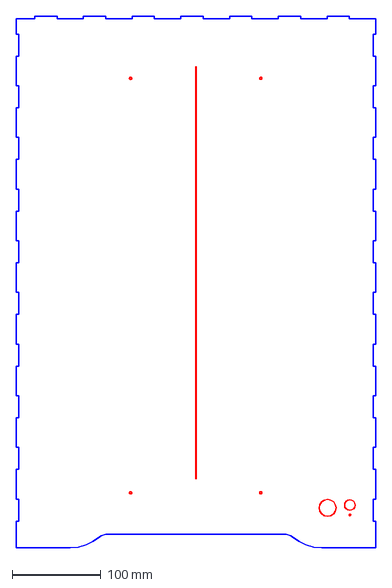
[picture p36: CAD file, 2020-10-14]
CAD/Plano de Corte/Peças Individuais/Externo/LAMP 400 - Fundo.dxf
406.1 x 600.1 mm

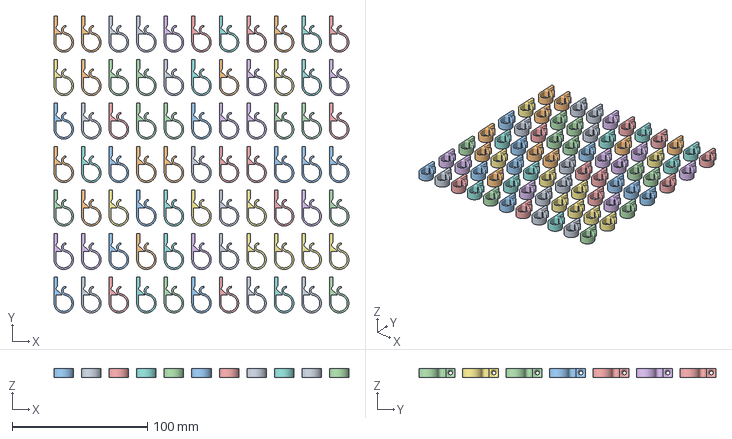
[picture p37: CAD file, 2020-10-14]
CAD/Impressao 3D/3MF/Prendedor Cabos - 77 PEÇAS - 1 LOTE.3mf
218.4 x 220.0 x 6.80 mm

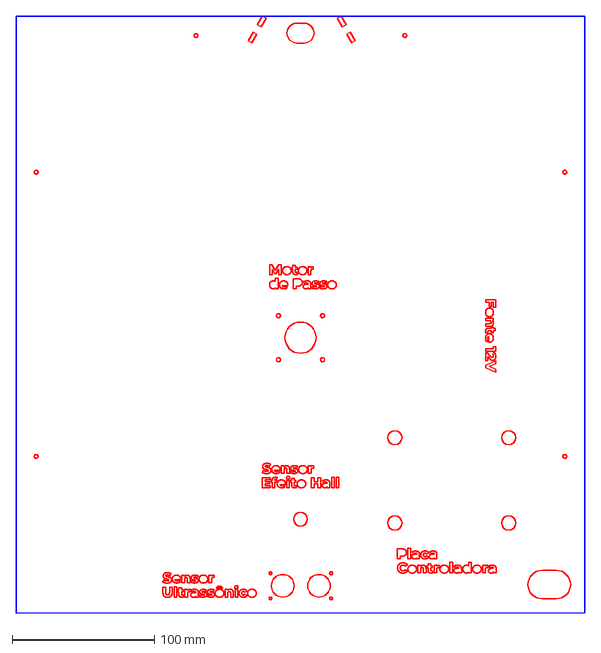
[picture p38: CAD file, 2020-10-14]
CAD/Plano de Corte/Peças Individuais/Externo/LAMP 400 - Topo Inferior.dxf
400.0 x 420.0 mm

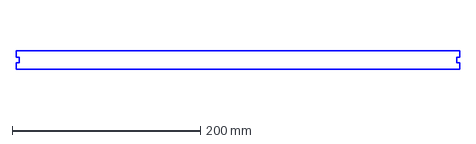
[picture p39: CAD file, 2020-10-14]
CAD/Plano de Corte/Peças Individuais/Externo/LAMP 400 - Aleta 3.dxf
471.1 x 20.2 mm

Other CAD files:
CAD/Impressao 3D/STL/Done/Suporte Lampada g13 com LDR - 20 PEÇAS - IMPRIMIR 2 LOTES.stl
CAD/Impressao 3D/3MF/Suporte Lampada g13 - 20 PEÇAS - IMPRIMIR 2 LOTES.3mf
CAD/Impressao 3D/3MF/Bucha Rolamento + Suporte Rolamento + Suporte Aro - IMPRIMIR 1 LOTE.3mf
CAD/Plano de Corte/Peças Individuais/Externo/LAMP 400 - Aleta 4.dxf
CAD/Impressao 3D/STL/Prendedor Cabos - 77 PEÇAS - 1 LOTE.stl
CAD/Plano de Corte/Peças Individuais/Externo/LAMP 400 - Aleta 2.dxf
CAD/Plano de Corte/Peças Individuais/Externo/LAMP 400 - Aro 2.dxf
CAD/Plano de Corte/Peças Individuais/Externo/LAMP 400 - Barreira.dxf
CAD/Plano de Corte/Peças Individuais/Externo/LAMP 400 - Base.dxf
CAD/Plano de Corte/Peças Individuais/Externo/LAMP 400 - Frente (1).dxf
CAD/Plano de Corte/Peças Individuais/Externo/LAMP 400 - Lateral Esquerda.dxf

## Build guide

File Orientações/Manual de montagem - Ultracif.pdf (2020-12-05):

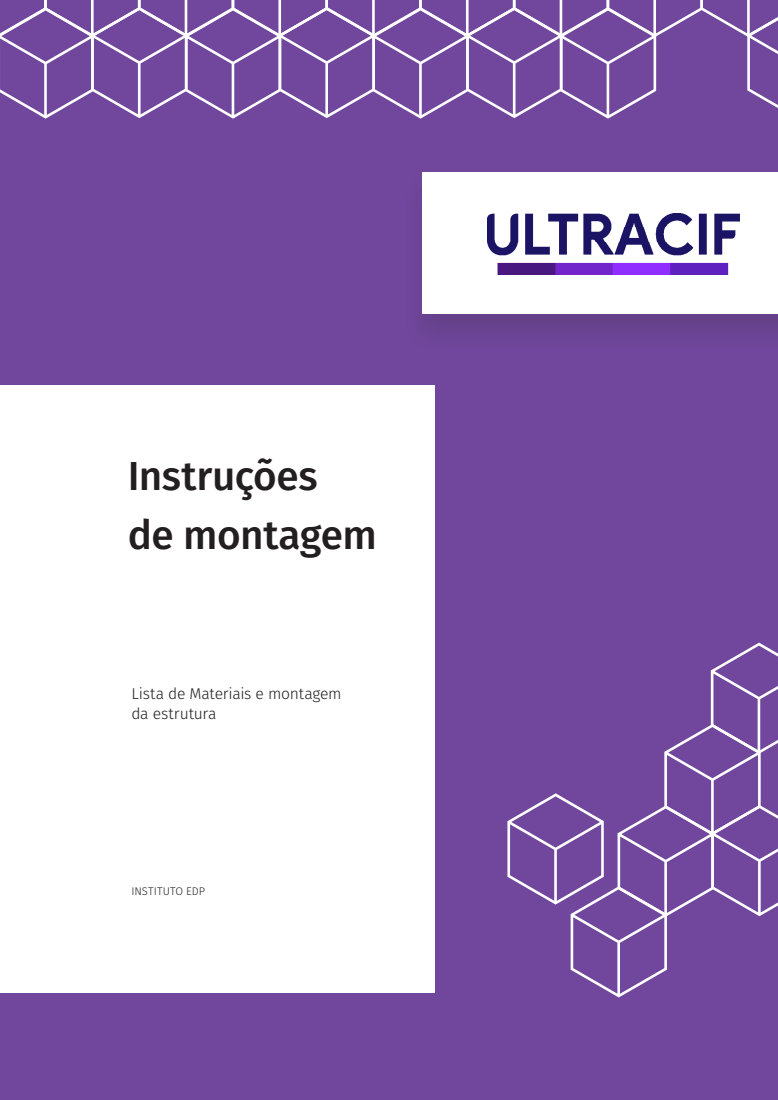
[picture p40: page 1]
Instruções de montagem; INSTITUTO EDP

Lista de Materiais e montagem
da estrutura

## ELETRONICA - PCB

DRIVER MOTOR DE PASSO | DRV8825 | 1
ARDUINO NANO | | 1
CAPACITOR | 100NF 50V | 2
CAPACITOR | 100UF 16V | 2
DIODO | 1N4001 | 1
LED VERDE | | 1
LED VERMELHO | | 1
DIODO | 1N4148 | 1
CONECTOR MODU 3 VIAS | | 3
CONECTOR MODU 4 VIAS | | 4
BORNE 2 VIAS | | 5
RELÉ 12V | | 1
TRANSISTOR | | 1
RESISTOR | 3K3 1/4W | 2
RESISTOR | 100 1/4W | 1
RESISTOR | 1K 1/4W | 3
REGULADOR 5V | LM7805 | 1
PCB | | 1

## DIVERSOS

MOTOR DE PASSO | 17HS4401 | 1
SENSOR EFEITO HALL | KY-003 | 1
IMA NEODIMIO | 10X3MM | 1
SENSOR ULTRASSONICO | HC-SR04 | 1

# Instruções Lista de materiais

2 | ULTRACIF

LDR | 5MM | 2
BOTÃO PULSADOR | | 1
BOTÃO GANGORRA | | 1
PORTA FUZIL | | 1
RABICHO 2 VIAS | 2 METROS | 1
CABO 0,75MM | METROS | 8
REATOR ELETRONICO | 60W | 2
FUSIVEL DE VIDRO 5X20 | 3A | 1
CABO FLAT | METROS | 1
MALHA NAUTICA | METROS | 2
FITA ALUMINIZADA | METROS | 1,2
SOQUETE LAMPADA | 2G11 | 2
LAMPADA UVC | 60W 2G11 | 2
MDF LAMINADO | 3MM | N/A
ROLAMENTO | 608 ZZ | 1
PARAFUSOS | M3X10MM | 32

## IMPRESSÃO 3D

SUPORTE ROLAMENTO | PETG | 1
BUCHA ROLAMENTO | PETG | 1
SUPORTE ARO ROTATORIO | PETG | 1
FIXADOR 90° | PETG | 12
PRENDEDOR DE CABOS | PETG | 8
GANCHO MASCARA | PETG | 1
PINOS DE SUPORTE PCB | PETG | 4
SUPORTE LAMPADA | PETG | 2

# Instruções Lista de materiais

ULTRACIF | 3

1

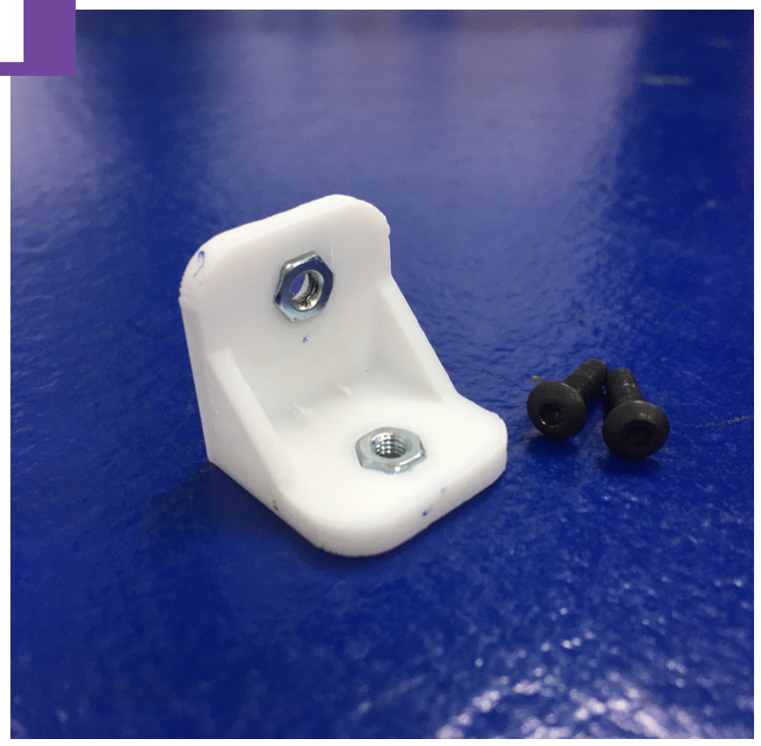
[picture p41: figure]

encaixe as porcas nos fixadores 90° graus
3

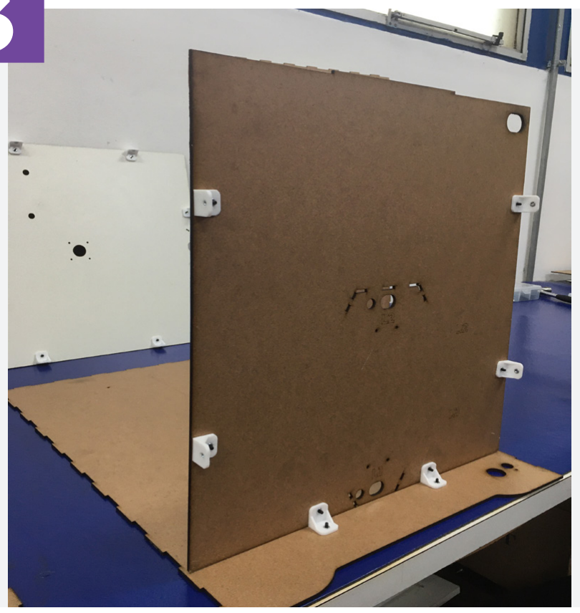
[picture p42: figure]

Parafuse as peças laterais nas peças de topo inferior e base

2

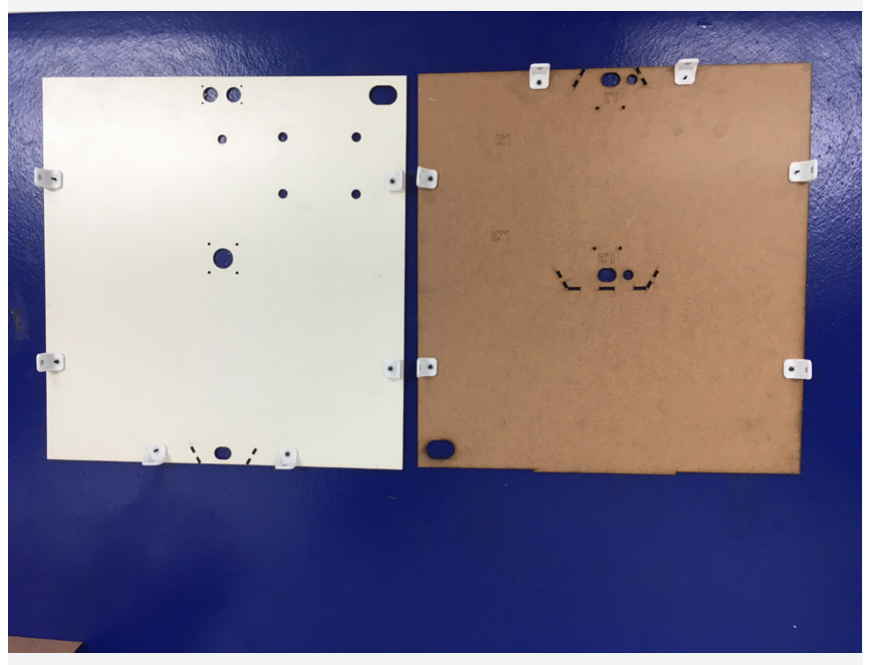
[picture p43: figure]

Parafuse os fixadores 90° graus nas peças de topo inferior e base
4

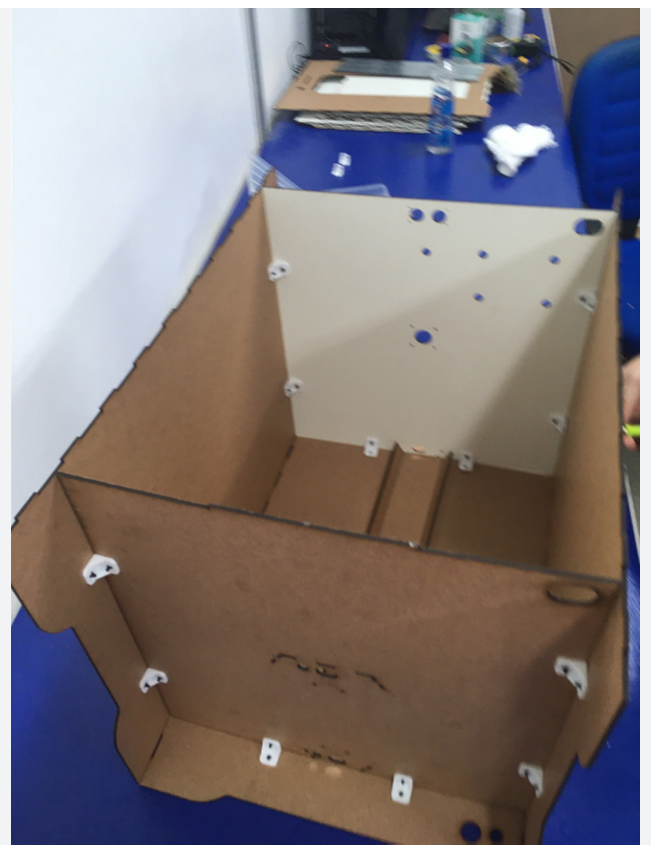
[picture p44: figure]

A estrutura após montada ficará da seguinte forma.

# Instruções Montagem

5

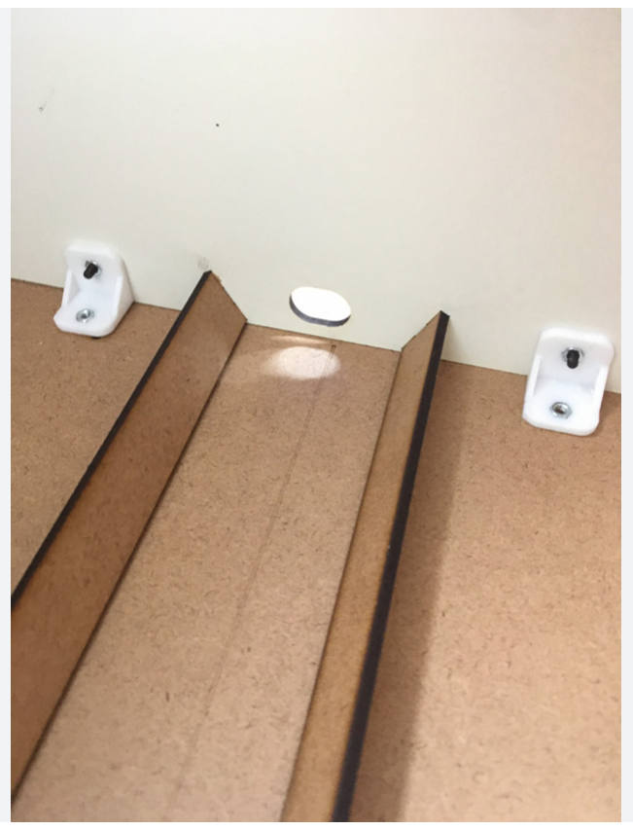
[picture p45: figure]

Encaixe as aletas traseiras nos enxaixes correspondentes e cole a fita aluminizada.
7

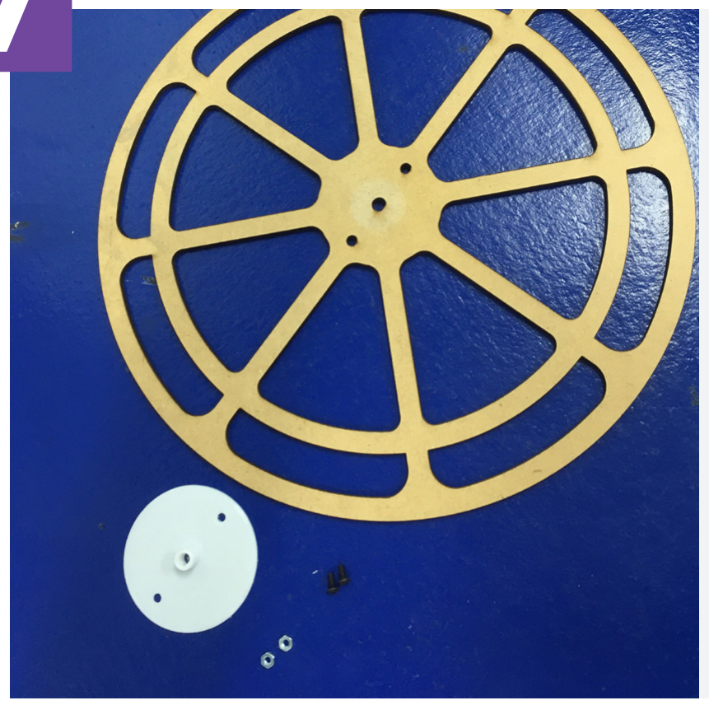
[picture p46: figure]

Parafuse o suporte no aro rotatório utilizando porca e parafuso.

6

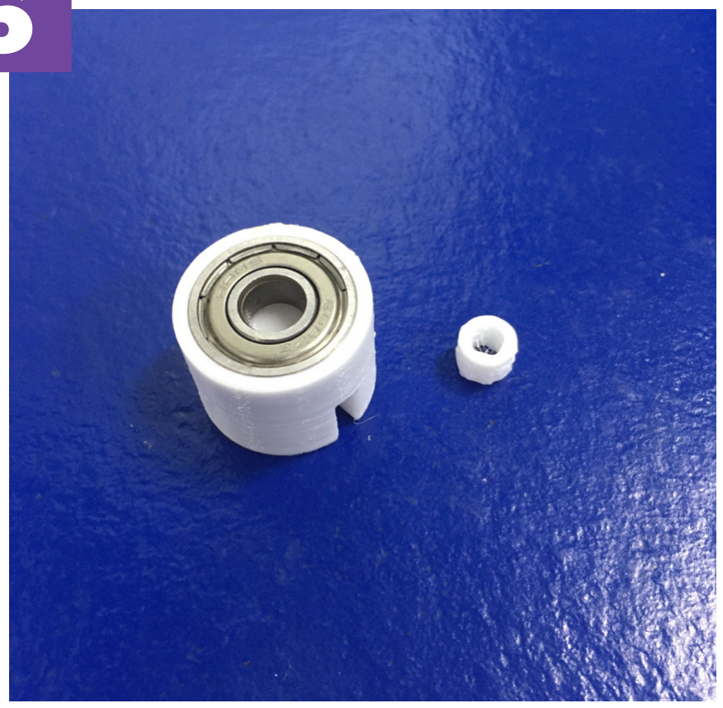
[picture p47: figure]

Encaixe o rolamento no suporte para rolamento e a bucha para encaixe do eixo do motor no centro do rolamento.
8

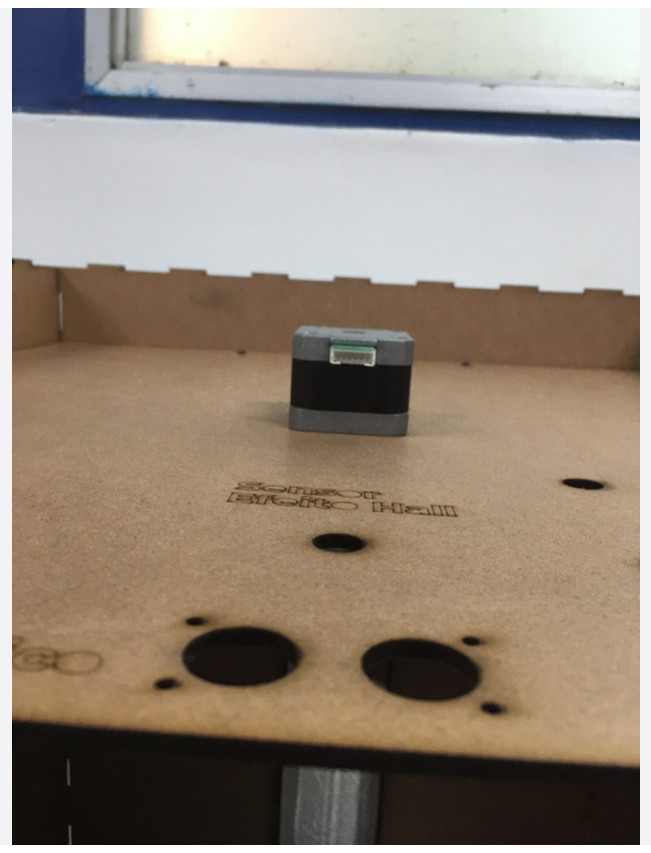
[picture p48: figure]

Encaixe e parafuse o motor NEMA 17 no topo inferior utilizando parafusos M3.

# Instruções Montagem

9

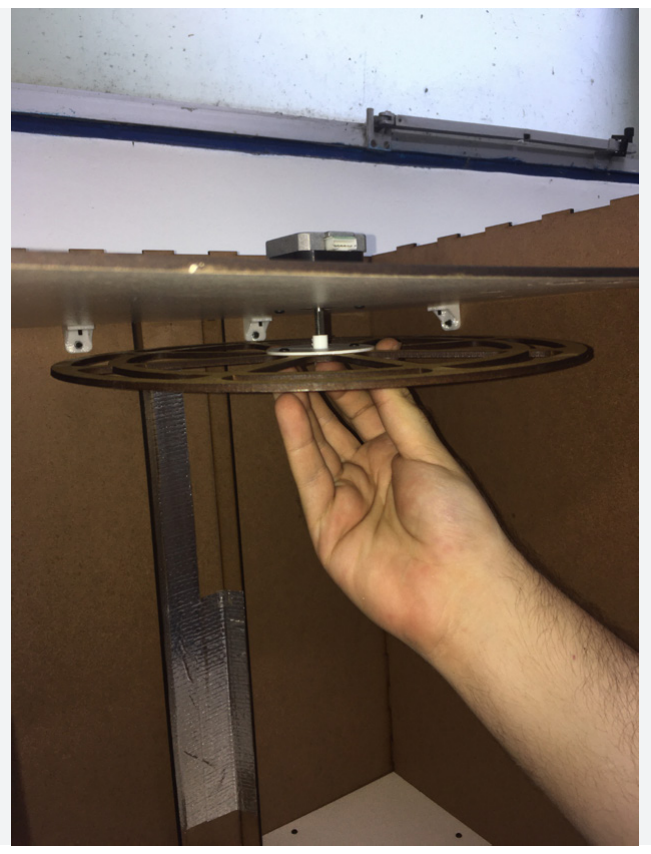
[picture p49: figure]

Encaixe o aro no eixo do motor NEMA 17 com a peça impressa em 3D virada para cima.
11

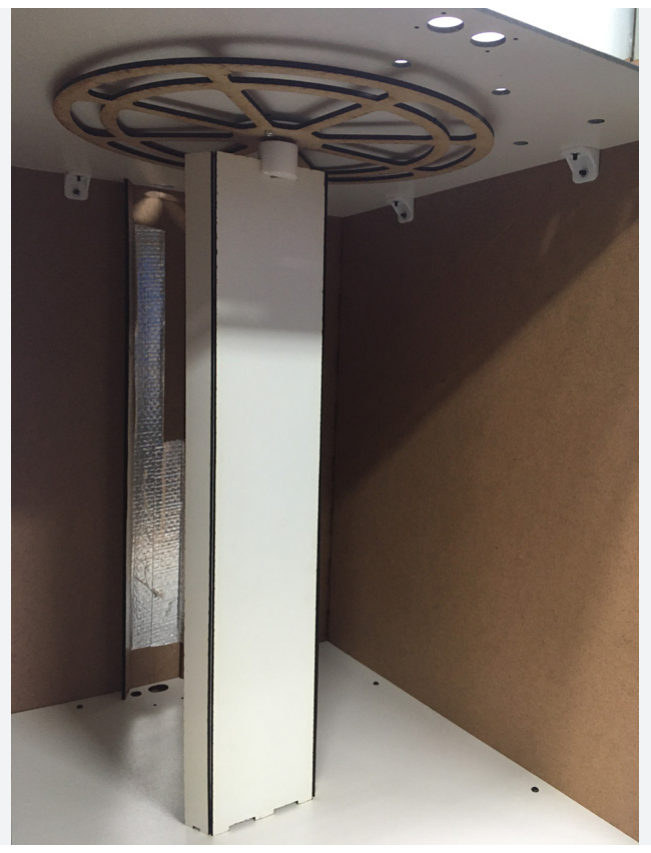
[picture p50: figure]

Encaixe a barreira na base e no suporte de rolamento do eixo do motor.

10

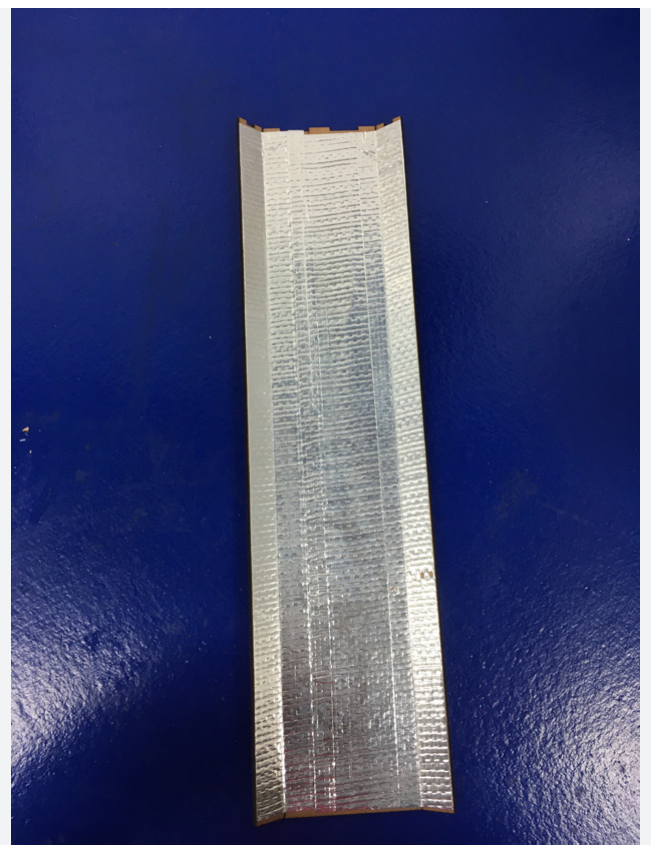
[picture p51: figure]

Junte as aletas e barreira cole a fita aluminizada nas peças da barreira.
12

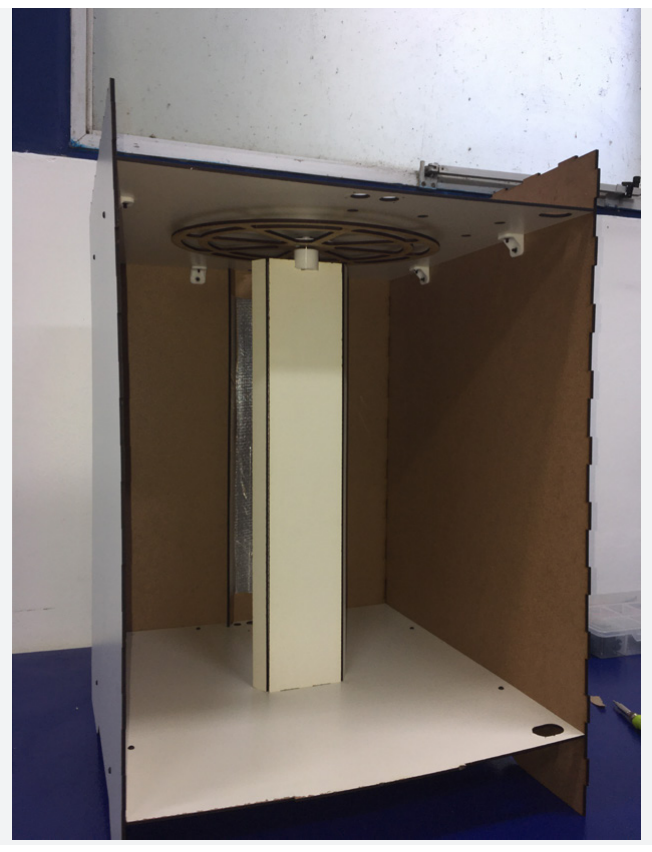
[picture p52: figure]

A estrutura após montada ficará da seguinte forma.

# Instruções Montagem

13
14

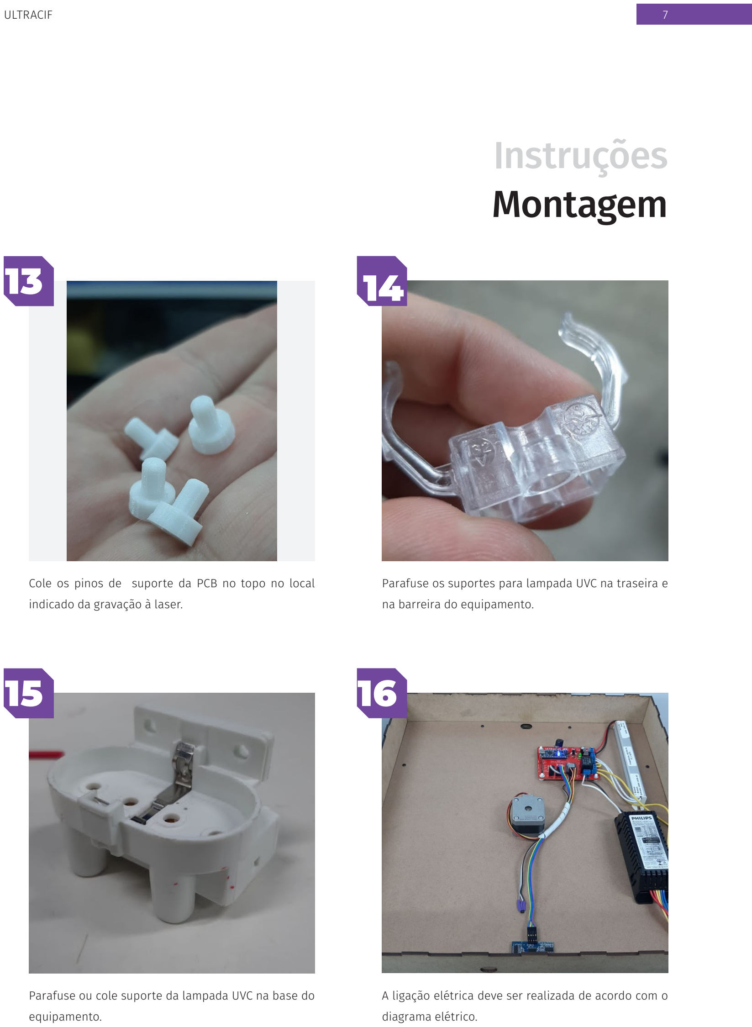
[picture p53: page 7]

Cole os pinos de suporte da PCB no topo no local indicado da gravação à laser.
15

Parafuse ou cole suporte da lampada UVC na base do equipamento.

Parafuse os suportes para lampada UVC na traseira e na barreira do equipamento.
16

A ligação elétrica deve ser realizada de acordo com o diagrama elétrico.

# Instruções Montagem

# Instruções Diagrama Elétrico

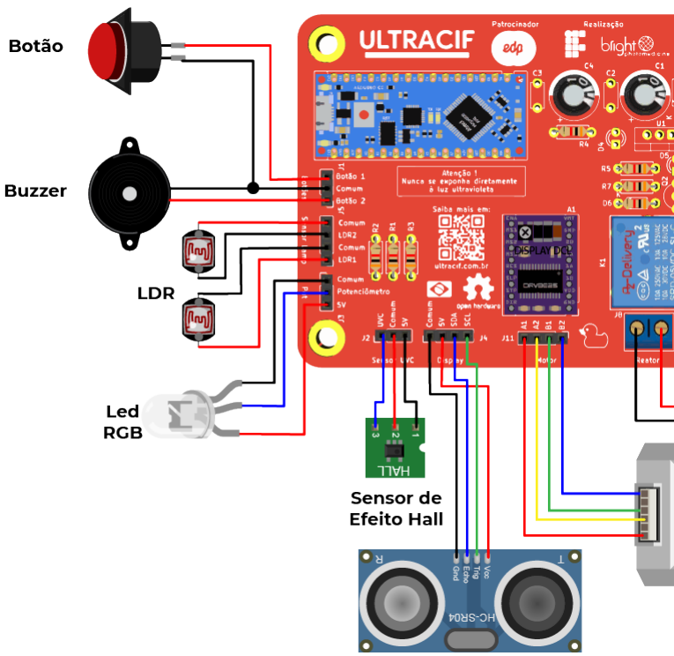
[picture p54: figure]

# Instruções Diagrama Elétrico

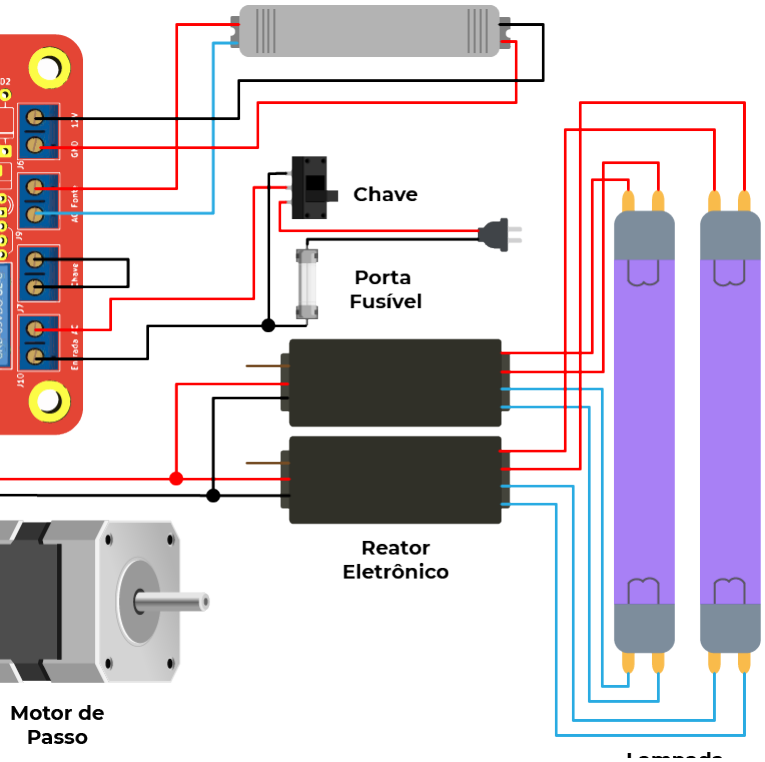
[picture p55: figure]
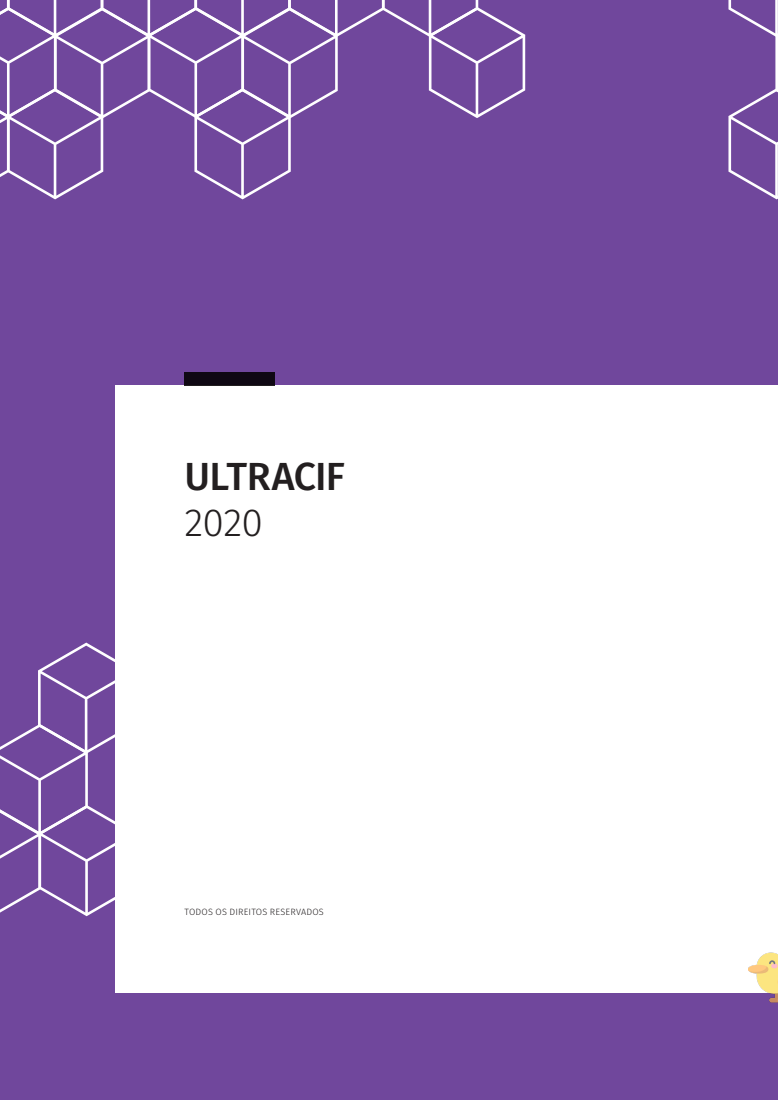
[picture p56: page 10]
ULTRACIF 2020

TODOS OS DIREITOS RESERVADOS

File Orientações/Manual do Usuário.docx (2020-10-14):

Imagem a ser gravada no equipamento para orientação ao usuário:

1) Gravada na face externa da barreira de madeira que fica no interior da estrutura;
2) Gravada na superfície externa do equipamento.

Partes componentes do sistema, do ponto de vista do usuário:

1 - Porta para acesso ao sistema de descontaminação.

2 - Gancho para fixação da máscara.

3 - Botão para acionar o sistema de descontaminação.

4 - Led Verde, para indicação de operação do sistema de descontaminação.

5 - Led Vermelho, para indicar falha do equipamento.

Instruções de Operação

1 - Pendure a máscara nos fixadores.

2 - Aperte o botão LIGAR.

3 - A máscara vai se movimentar para a câmara interna e será descontaminada em 5 minutos.

4 - O luz indicadora verde começará a piscar, indicando o início do processo de descontaminação. Ao final do processo ela ficará acesa até a máscara ser trazida até a porta do equipamento, podendo ser retirada.

Orientações Gerais

1 - A luz indicadora vermelha representa uma falha do equipamento, podendo indicar que uma lâmpada queimou.

2 - Nunca coloque a mão no interior da câmara, pois a luz ultravioleta UVC é nociva aos tecidos humanos.

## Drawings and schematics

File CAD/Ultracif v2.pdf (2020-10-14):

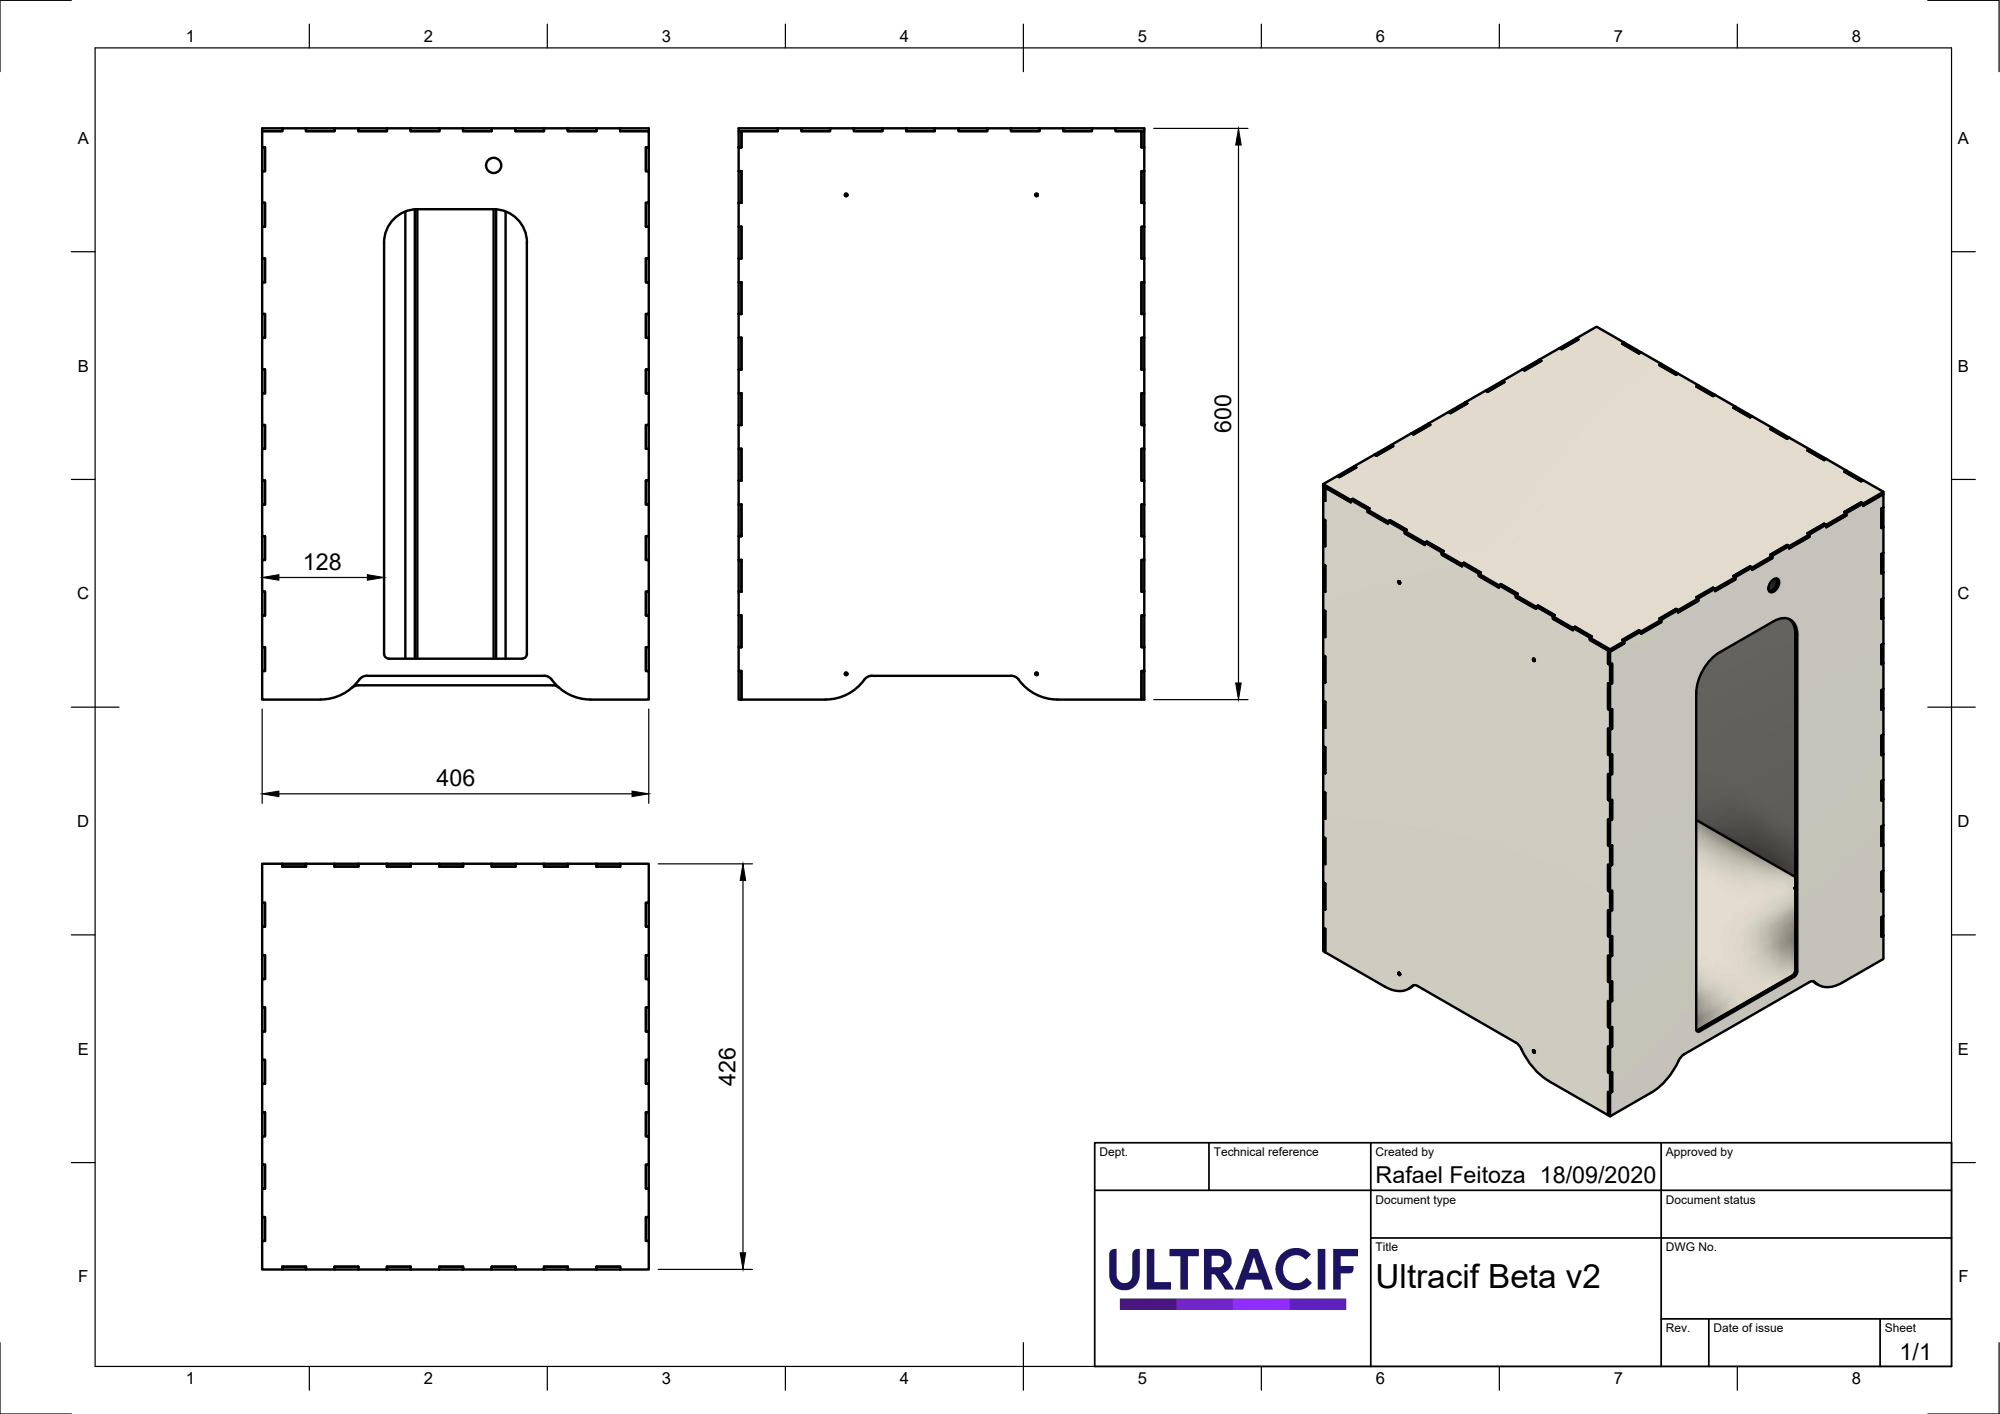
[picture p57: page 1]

Dept. | Technical reference | Created by Rafael Feitoza 18/09/2020 | Approved by

Document type | Document status

Title Ultracif Beta v2 | DWG No.

Rev. | Date of issue | Sheet 1/1

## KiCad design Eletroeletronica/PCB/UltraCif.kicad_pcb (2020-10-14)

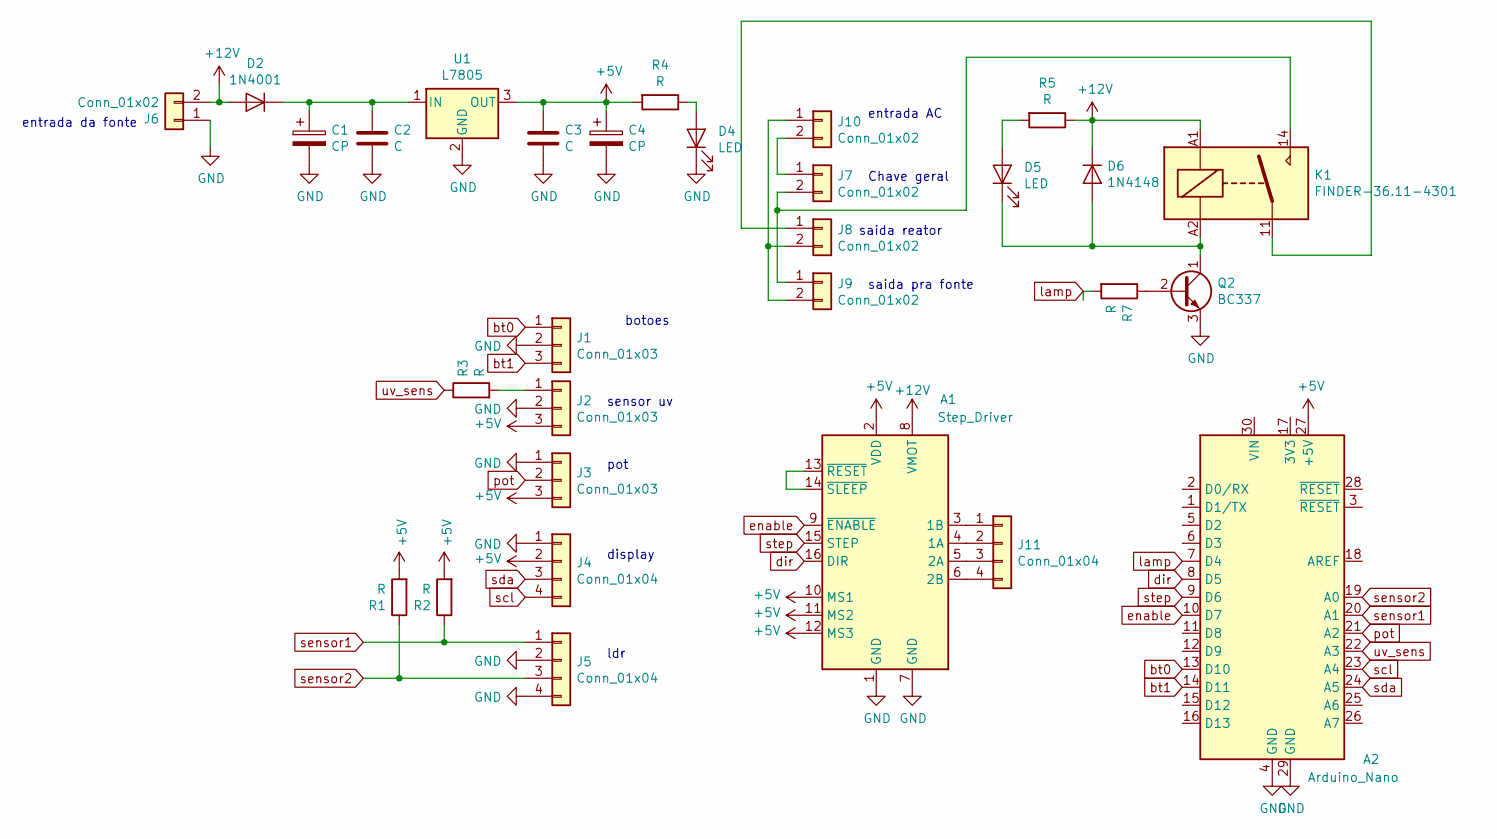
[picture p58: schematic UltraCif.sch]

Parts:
A1: Step_Driver; Pololu_Breakout-16_15.2x20.3mm
A2: Arduino_Nano
C1, C4: CP; CP_Radial_D10.0mm_P5.00mm
C2, C3: C; C_Disc_D5.0mm_W2.5mm_P5.00mm
D2: 1N4001; D_DO-41_SOD81_P10.16mm_Horizontal
D4, D5: LED; LED_D3.0mm
D6: 1N4148; D_DO-35_SOD27_P7.62mm_Horizontal
J1, J2, J3: Conn_01x03; PinHeader_1x03_P2.54mm_Vertical
J4, J5, J11: Conn_01x04; PinHeader_1x04_P2.54mm_Vertical
J6, J7, J8, J9, J10: Conn_01x02; TerminalBlock_bornier-2_P5.08mm
K1: FINDER-36.11-4301; Relay_SPDT_Finder_36.11
Q2: BC337; TO-92_Inline_Wide
R1, R2, R3, R4, R5, R7: R; R_Axial_DIN0207_L6.3mm_D2.5mm_P7.62mm_Horizontal
U1: L7805; TO-220-3_Vertical

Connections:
+5V: A1.2 (VDD), A1.10 (MS1), A1.11 (MS2), A1.12 (MS3), A2.27 (+5V), C3.1, C4.1, J2.3, J3.3, J4.2, R1.2, R2.2, R4.2, U1.3 (OUT)
+12V: A1.8 (VMOT), D2.2 (A), D6.1 (K), J6.2, K1.A1, R5.1
GND: A1.1 (GND), A1.7 (GND), A2.4 (GND), A2.29 (GND), C1.2, C2.2, C3.2, C4.2, D4.1 (K), J1.2, J2.2, J3.1, J4.1, J5.2, J5.4, J6.1, Q2.3 (E), U1.2 (GND)
unnamed: A1.3 (1B), J11.1
unnamed: A1.4 (1A), J11.2
unnamed: A1.5 (2A), J11.3
unnamed: A1.6 (2B), J11.4
unnamed: A1.13 (~RESET), A1.14 (~SLEEP)
unnamed: C1.1, C2.1, D2.1 (K), U1.1 (IN)
unnamed: D4.2 (A), R4.1
unnamed: D5.1 (K), D6.2 (A), K1.A2, Q2.1 (C)
unnamed: D5.2 (A), R5.2
unnamed: J2.1, R3.2
unnamed: J7.2, J9.1, K1.14
unnamed: J8.1, K1.11
unnamed: J8.2, J9.2, J10.1
unnamed: J7.1, J10.2
unnamed: Q2.2 (B), R7.1
bt0: A2.13 (D10), J1.1
bt1: A2.14 (D11), J1.3
dir: A1.16 (DIR), A2.8 (D5)
enable: A1.9 (~ENABLE), A2.10 (D7)
lamp: A2.7 (D4), R7.2
pot: A2.21 (A2), J3.2
scl: A2.23 (A4), J4.4
sda: A2.24 (A5), J4.3
sensor1: A2.20 (A1), J5.1, R2.1
sensor2: A2.19 (A0), J5.3, R1.1
step: A1.15 (STEP), A2.9 (D6)
uv_sens: A2.22 (A3), R3.1

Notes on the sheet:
entrada AC
Chave geral
saida reator
saida pra fonte
entrada da fonte
botoes
sensor uv
pot
display
ldr

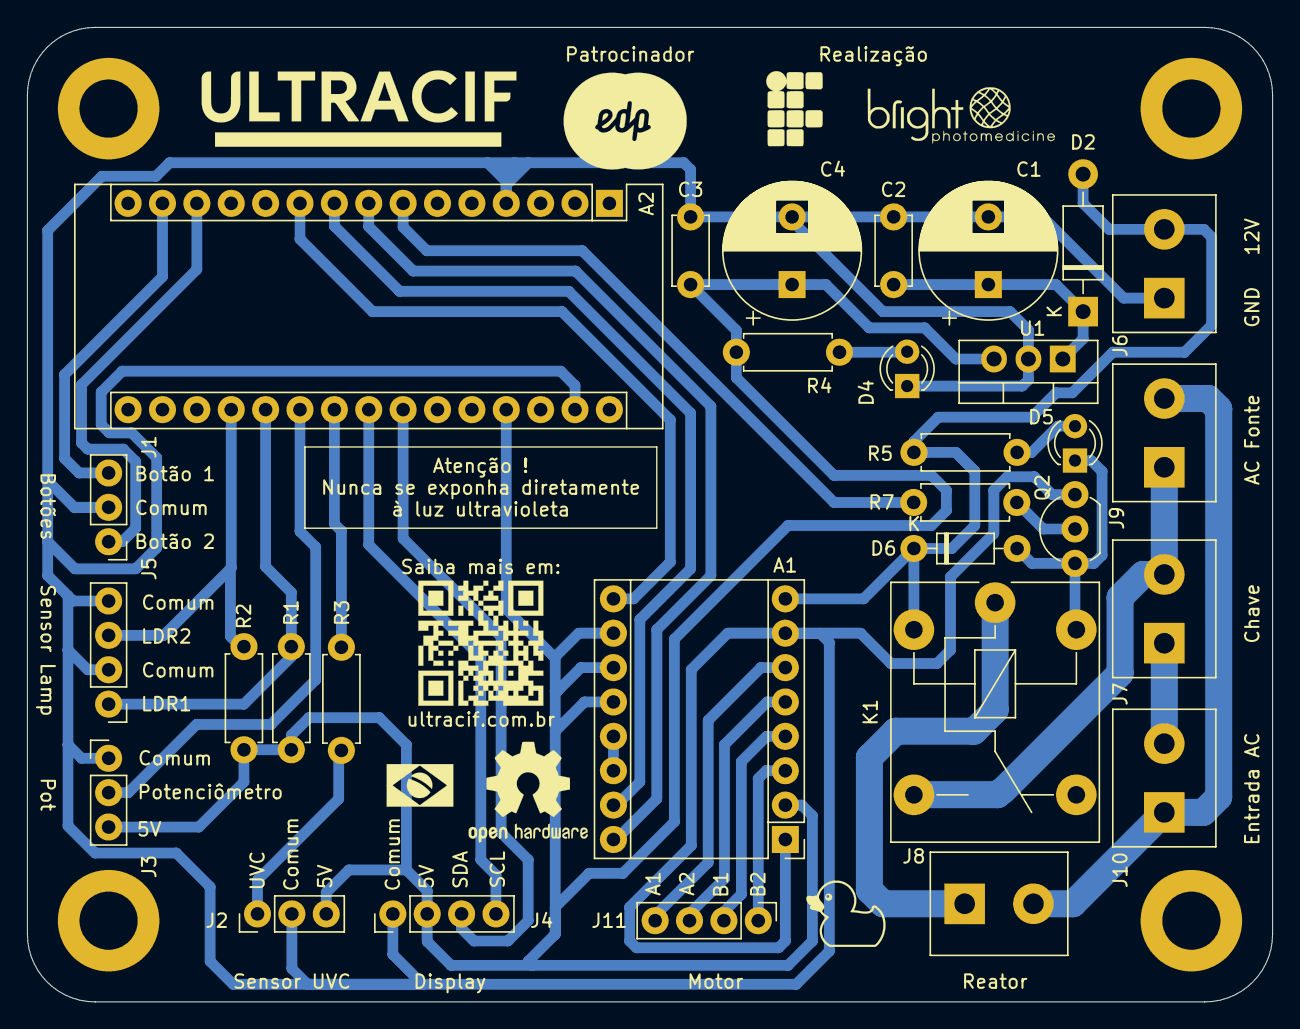
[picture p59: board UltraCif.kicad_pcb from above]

Board: 2 copper layers, 92.0 x 72.0 mm, 30 parts (0 on the bottom side), 30 nets.

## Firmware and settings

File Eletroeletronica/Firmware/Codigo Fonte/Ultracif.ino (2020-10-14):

/*
  Firware do equipamento ULTRACIF
  v0.1 - 16/09/202
  @cadupalmieri
*/

//Coloque o tempo de descontaminação ( em segundos) na configuração abaixo
#define tempo_uv 300 //em segundos

//Configurações do motor
#include "BasicStepperDriver.h"
#define MOTOR_STEPS 200
#define RPM 0.05
#define MICROSTEPS 32
#define DIR 5
#define STEP 6
#define SLEEP 7
BasicStepperDriver stepper(MOTOR_STEPS, DIR, STEP, SLEEP);

//Configurações entradas e saidas.
#define buzzer 3
#define lampada  4
#define botao  10

#define ldr_1 A2
#define ldr_2 A0
#define ldr_3 A1

#define hall   A3
#define led_g  A4
#define led_r  A5
#define led_b  11

//Variaveis
long tempo;
bool start = 1;
bool libera = 0;
long time_pisca;

void setup() {
  Serial.begin(9600);

  pinMode(lampada, OUTPUT);
  pinMode(buzzer, OUTPUT);

  pinMode(led_r, OUTPUT);
  pinMode(led_g, OUTPUT);
  pinMode(led_b, OUTPUT);

  pinMode(botao, INPUT_PULLUP);

  stepper.begin(RPM, MICROSTEPS);
  stepper.setEnableActiveState(LOW);


  sensor_lampadas();
  delay(500);
}

void loop() {
  if (!digitalRead(botao) &  start) {
    sensor_lampadas();
    if (libera) {
      start = 0;

      Serial.println("Inicia Ciclo") ;

      stepper.enable();
      stepper.begin(5, MICROSTEPS);
      stepper.move(-20 * MICROSTEPS);

      while (analogRead(hall) < 225) {
        stepper.move(1 * MICROSTEPS);
        delay(10);
      }

      Serial.println("Bateu sensor inicio") ;
      // Zerou
      digitalWrite(buzzer, HIGH);
      delay(500);
      digitalWrite(buzzer, LOW);


      stepper.begin(10, MICROSTEPS);
      stepper.move(80 * MICROSTEPS);

      delay(100);

      digitalWrite(lampada, HIGH);


      Serial.println("Inicia Descontaminacao") ;
      stepper.begin(1, MICROSTEPS);
      long start_uv = millis();
      azul();

      float rpm = (40.0 * 3) / (tempo_uv / 0.1) ;
      Serial.print("rpm = ");
      Serial.println(rpm, 10);

      stepper.begin(rpm, MICROSTEPS);
      for (int i = 0 ; i < 40; i++) {

        stepper.move(1 * MICROSTEPS);
        delay(10);

        if ((millis() - time_pisca)  > 5000) {
          digitalWrite(buzzer, HIGH);
          azul();
          delay(100);
          digitalWrite(buzzer, LOW);
          apagado();
          time_pisca = millis();
        }
      }
      Serial.println("Fim Descontaminacao") ;
      Serial.print("Tempo_total = ");
      Serial.println((millis() - start_uv) / 1000);

      digitalWrite(lampada, LOW);

      stepper.begin(10, MICROSTEPS);

      while (analogRead(hall) < 225) {
        stepper.move(1 * MICROSTEPS);
        delay(10);
      }

      Serial.println("Bateu sensor fim ") ;
      for (int i = 0 ; i < 10; i++) {
        digitalWrite(buzzer, HIGH);
        delay(80);
        digitalWrite(buzzer, LOW);
        delay(40);
      }
      azul();
      stepper.disable();
      digitalWrite(buzzer, LOW);
      delay(1000);
      verde();
      start = 1;
      Serial.println("Fim Ciclo") ;
    }
  }
}



void sensor_lampadas() {
  digitalWrite(lampada, HIGH);
  delay(500);

  float l_1 = 0, l_2 = 0, l_3 = 0;
  for (int i = 0 ; i < 100; i++) {
    l_1 = analogRead(ldr_1) * 5 / 1023.0;
    l_2 = analogRead(ldr_2) * 5 / 1023.0;
    l_3 = analogRead(ldr_3) * 5 / 1023.0;
    delay(10);
  }
  digitalWrite(lampada, LOW);

  Serial.print("L1 = ");
  Serial.print(l_1);
  Serial.print("   L2 = ");
  Serial.print(l_2);
  Serial.print("   L3 = ");
  Serial.println(l_3);
  delay(100);
  if (l_1 >= 4.5 || l_2 >= 4.5 || l_3 >= 4.5) {
    Serial.println("ha uma lampada queimada");
    apagado();
    digitalWrite(buzzer, HIGH);
    vermelho();
    delay(3000);
    digitalWrite(buzzer, LOW);
    libera = 0;
  }
  else {
    Serial.println("Lampadas ok");
    verde();
    digitalWrite(buzzer, LOW);
    libera = 1;
  }
}


void roxo() {
  digitalWrite(led_r, HIGH);
  digitalWrite(led_g, LOW);
  digitalWrite(led_b, HIGH);
}

void verde() {
  digitalWrite(led_r, LOW);
  digitalWrite(led_g, HIGH);
  digitalWrite(led_b, LOW);
}

void vermelho() {
  digitalWrite(led_r, HIGH);
  digitalWrite(led_g, LOW);
  digitalWrite(led_b, LOW);
}

void azul() {
  digitalWrite(led_r, LOW);
  digitalWrite(led_g, LOW);
  digitalWrite(led_b, HIGH);
}

void branco() {
  digitalWrite(led_r, HIGH);
  digitalWrite(led_g, HIGH);
  digitalWrite(led_b, HIGH);
}

void apagado() {
  digitalWrite(led_r, LOW);
  digitalWrite(led_g, LOW);
  digitalWrite(led_b, LOW);
}
